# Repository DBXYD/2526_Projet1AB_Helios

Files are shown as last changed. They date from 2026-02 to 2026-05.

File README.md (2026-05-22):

# 2526_Projet1AB_Helios
Projet de 1ère année ENSEA sur un stroboscobe RGB
## Sommaire
* [Cahier des charges](#cahier-des-charges)
* [Matériels utilisés](#matériels-utilisés)
* [Organisation du projet](#organisation-du-projet)
  * [Architecture PCB](#architecture-pcb)
* [Journal de Bord du projet](#journal-de-bord-du-projet)
* [Répartition des Tâches](#répartition-des-tâches)
* [Membres du projet](#membres-du-projet)
## Cahier des charges
**Project scénique à LED**
* Strobe RGBW haute puissance (100 W minimum)
* Pilotage DMX512 (standard éclairage)
* interface utilisateur intuitive
* Modifier la fréquence d'allumage des LEDs
* Modes :
    * Intensité R/G/B
    * Strobe (fréquence, intensité)
* Sécurité thermique + électrique

**Contraintes**
* Alimentation secteur
* Fiabilité (usage scène)
* Dissipation thermique sérieuse
* Respect du DMX (isolation, timing)

## Présentation du projet
* [Présentation Hardware](https://github.com/DBXYD/2526_Projet1AB_Helios/blob/master/Presentation/Projet%201AB%20-%20H%C3%A9lios.pdf)
* [Architecture du Code](https://github.com/DBXYD/2526_Projet1AB_Helios/blob/master/Presentation/Projet1AB_Helios_Code.pdf) (DMX 512)

## Diagrammes
* [Diagrammes](https://github.com/DBXYD/2526_Projet1AB_Helios/tree/master/Presentation/Diagrammes)

## Matériels utilisés
| **Composant** | **Référence** |
| :--- | :--- |
| LEDs 98 (x3 couleurs) | [150505M173300](https://github.com/DBXYD/2526_Projet1AB_Helios/blob/master/datasheet/Datasheets%20du%20projet/LED_150505M173300.pdf) |
| 6 Driver | [LM3404](https://github.com/DBXYD/2526_Projet1AB_Helios/blob/master/datasheet/Datasheets%20du%20projet/lm3404.pdf) |
| Microcontrolleur | [STM32F103C6T6A LQFP-48](https://github.com/DBXYD/2526_Projet1AB_Helios/blob/master/datasheet/Datasheets%20du%20projet/stm32f103c6.pdf) |
| DMX512 | Mâle: [NC3MAAH](https://github.com/DBXYD/2526_Projet1AB_Helios/blob/master/datasheet/Datasheets%20du%20projet/nc3maah(DMX512M).pdf) Femelle: [NC3FAAH](https://github.com/DBXYD/2526_Projet1AB_Helios/blob/master/datasheet/Datasheets%20du%20projet/nc3faah(DMX512F).pdf) |
| Power Module WPME-FDSM | [173950536](https://github.com/DBXYD/2526_Projet1AB_Helios/blob/master/datasheet/Datasheets%20du%20projet/Power_Module_WPME-FDSM_173950536.pdf) |
| LOW DROPOUT LINEAR REGULATOR | [AZ1117CH2-TRG1](https://github.com/DBXYD/2526_Projet1AB_Helios/blob/master/datasheet/Datasheets%20du%20projet/AZ1117CH2-3.3TRG1.pdf) | 
| Ecran OLED | [OLED Dipslay](https://github.com/DBXYD/2526_Projet1AB_Helios/blob/master/datasheet/Datasheets%20du%20projet/SBC-OLED01_Datasheet_2022-01-06.pdf) |
| Alimentation | 24V / 5A | 
| Résistances | 2 x 1 kΩ ; 5 x 10 kΩ ; 2 x 1,6 kΩ ; 6 x 100 kΩ |
| Inductances | 6 x 18 uH |
| Condensateurs | 18 x 100 nF ; 2 x 1 uF ; 3 x 10 uF ; 1 x 22 uF ; 2 x 10 nF |
| LEDs SMD | 2 x [LED_0805_2012Metric](https://github.com/DBXYD/2526_Projet1AB_Helios/blob/master/datasheet/Datasheets%20du%20projet/LED_0805_2012Metric.pdf) |
| Boutons poussoirs | 3 x [Bouton ](https://github.com/DBXYD/2526_Projet1AB_Helios/blob/master/datasheet/Datasheets%20du%20projet/6x6_mm_sw_switches.pdf) |
| Puce MAX485E | [Puce](https://github.com/DBXYD/2526_Projet1AB_Helios/blob/master/datasheet/Datasheets%20du%20projet/MAX1487E-MAX491E.pdf) |
| Connecteur AMASS | [Connecteur 1](https://github.com/DBXYD/2526_Projet1AB_Helios/blob/master/datasheet/Datasheets%20du%20projet/XT30U-M_AMASS_Datasheet.pdf)|
| Connecteur PinHeader | [Connecteur 2](https://github.com/DBXYD/2526_Projet1AB_Helios/blob/master/datasheet/Datasheets%20du%20projet/connecteur%20pinheader.pdf)|

## Organisation du projet

### Architecture PCB:
* **Alimentation** : Power Module WPME-FSDM, AZ1117CH2-TRG1
* **Contrôle** : Microcontrolleur avec interface OLED
* **Pilotage LEDs** : drivers pour les chaînes R, G, B (2 drivers par couleur)
* **Protection et sécurité** : TODO (fusible, dissipateurs thermiques, diode)

### BOM:
[Matériel utilisé](https://github.com/DBXYD/2526_Projet1AB_Helios/blob/master/Hardware/KICAD_HELIOS/bom/ibom.html)

## Journal de Bord du projet 
[Journal de Bord](https://github.com/DBXYD/2526_Projet1AB_Helios/blob/master/journal_de_bord.md)

## Répartition des Tâches
| **Nom Prénom** | **Tâche(s)** |
| :--- | :--- |
| **TRITON Kylian** | Schématique du PCB, Routage du PCB, Valeurs des composants (fichier python), Mise à jour du Github, Recherche des composants |
| **RIEU Pierric** | Software des drivers (intégralité des codes), PCB |
| **BAILLEUL Sara** | Soudage, Vérification des empreintes sur PCB, Commande des composants et bon de commande du PCB, Recherche des composants (soudage et datasheet), Mise à jour du GitHub, Diagramme Hardware |
| **LEIRAS Clara** | LEDs (Schématique du PCB), Soudage, Recherche des composants (datasheet) |
| **GOMRI Samuel** | Recherche des composants |

## Membres du projet
| | | | | |
|:---:|:---:|:---:|:---:|:---:|
|  |  |  |  |  | 
| [**@TritonKylian**](https://github.com/TritonKylian)<br>TRITON Kylian| [**@PierricRieu**](https://github.com/PierricRieu)<br>RIEU Pierric | [**@sblikeice**](https://github.com/sblikeice)<br> BAILLEUL Sara | [**@claralrs9**](https://github.com/claralrs9)<br>LEIRAS Clara| [**@sgomri**](https://github.com/sgomri)<br>GOMRI Samuel |

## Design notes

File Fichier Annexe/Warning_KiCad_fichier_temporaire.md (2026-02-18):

# Warning KiCad (Document temporaire)
## cathode
la cathode peut être branché à rien (il n'y a plus aucune erreur), /edit/ normalement c'est ok.
## LED Footprint 
could be wrong for the D1 and D2
## Ecran
Doit-on utiliser un socket ou bien alors un connecteur pour l'écran (practicité etc à voir ou alors le brancher en usb???)
## Résistance
Vérifier les bonnes valeurs des empreintes: 
ie: 2010 pour les grosses et 1210 pour autres
et pour les résistances de pull up 0805
## Bouton 
jsp ce qu'ils ont de dispo à l'école mais j'ai assumé qu'ils en ont pleins différents (j'ai ni datasheet ni bouton sur l'excel)
# Schéma 
## LED arragement 
Pour le soudage il faut obligatoirement faire un schéma à partir des connections avant de les faire puisque les leds ne sont pas aligné correctement il faut les remettre en place

**Auteur :** Triton Kylian
**Date :** 19 Février 2026
**Statut :** En attente de validation des empreintes et du schéma dans l'intégralité

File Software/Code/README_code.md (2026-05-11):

# 2526_Projet1AB_Helios
Projet de 1ere année ENSEA sur un strobe

* TRITON Kylian
* RIEU Pierric
* BAILLEUL Sara
* LEIRAS Clara
* GOMRI Samuel

## CODE POUR ALLUMER LES LEDS

* Code pour allumer la led (Red) Rouge
* Code pour allumer la led (Green) Vert
* Code pour allumer la led (Blue) Bleu
* Code pour Dimmer(intensité)
* Code pour Shutter (fréquence)

* Penser à codé l'addresse pour chaque LED 512B envoyé 20 fois par s

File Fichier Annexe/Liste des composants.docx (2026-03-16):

Liste des composants et quantité nécessaire :

Empreinte

En stock : sur l’Excel

P : demander à Patricia avant pour savoir si ce n’est pas en stock autre part

Microcontrôleur : STM32F103C6TX (1) → à commander

Condensateurs (26) :

- 100 nF (18) → en stock → 0603/50V sinon 0402
- 1 uF (2) → en stock → 0402 (si pas plus de 10V à l’endroit où il est)
- 10 uF (3) → (1 à côté du 24V, donc à commander MLCCs → 50V max/1206) et 0603/0805 (kit) (+5V) → 2 C
- 22 uF (1) → en stock (0805)
- 10 nF (2) → en stock → 0402

LEDs :

- Celle : LED_0805_2012Metric (2) → à voir, à commander P
- Pour l’éclairage : LEDWL-SFTW_5050_PLCC6 (98x3) / 150505M173300 → à commander

Connecteurs :

- Mâle : NC3MAAH (1) → en stock (boîte du projet)
- Femelle : NC3FAAH (1) → en stock (boîte du projet)
- Pour contrôler certains labels : Conn_ST_STDC14 (1) → en stock (normalement) P

lien DMX et microcontrôleur : MAX485E (1) → à commander P

Ecran OLED (1) → en stock

Bobines (6) :

- 68 uH (2) (1210) → en stock
- 18 uH (4) (1210) → à commander P

Résistances (15) :

- 1 kΩ (2) (1210) → à commander (en stock : 1206/0603/0402) P
- 10 kΩ (5) (1210 x4 et 0805x1) → 1210 à commander et 0805 en stock P
- 1,6 kΩ (2) (1210) → à commander P
- 100 kΩ (6) (2010) → à commander (en stock : 1206/0805) P

Bouton poussoir (3) → en stock

Drivers (6) :

- LM3404MA (6) → en stock (8)

Alimentation :

- AMS1117-3.3 (1) → à commander P
- R-78B5.0-2.0 (1) → à commander (il n’y en a plus en stock sur le Excel) P

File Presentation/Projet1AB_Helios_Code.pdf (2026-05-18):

# Projet1AB Helios

# Architecture du code

# Table des matières

## 1. Architecture globale 2. DMX512 : explication 3. Le module DMX 4. Le module DMX_PARSE 5. Le module STROBE 6. Difficultés rencontrées et apprentissages 7. Bibliographie

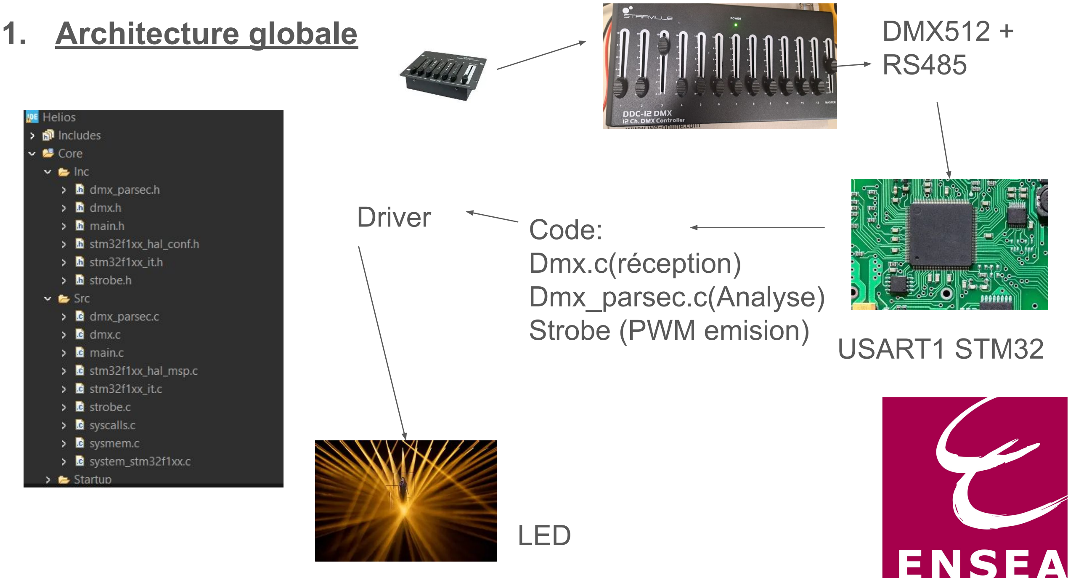
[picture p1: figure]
Architecture globale; DMX512 +; USART1 STM32; Driver; LED; Code: Dmx.c(réception) Dmx_parsec.c(Analyse) Strobe (PWM emision)

La norme DMX512 fonctionne par envoi d’octets pour chaque channel (donc de 0 à 255 codé sur 8 bits).

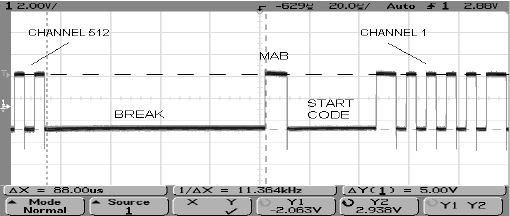
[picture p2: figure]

Cela va nous permettre d’établir l’intensité de chaque channel avec une PWM sur notre driver, selon la formule :

intensité = (valeur du channel × intensité du master) / 255

2. DMX512 : Explication | La norme DMX512 est un protocole d’éclairage numérique
| utilisé dans le domaine du spectacle et de la scène. Elle repose sur une communication série RS-485.Le protocole DMX512 permet de transmettre jusqu’à 512 canaux et fonctionne selon une architecture maître → esclaves : une console maître peut commander plusieurs équipements esclaves. Nous utilisons le RS-485 et non le RS-422 car le RS-485 est plus adapté aux systèmes DMX. Bien que les deux utilisent une transmission différentielle, le RS-485 permet d’avoir plusieurs équipements sur le même bus, contrairement au RS-422 qui ne supporte qu’un seul émetteur. Ainsi, plusieurs appareils peuvent être connectés sur la même ligne : projecteurs, strobes, machines à fumée, etc. Le RS-485 possède également une forte immunité aux parasites électriques et est adapté aux communications sur de longues distances.

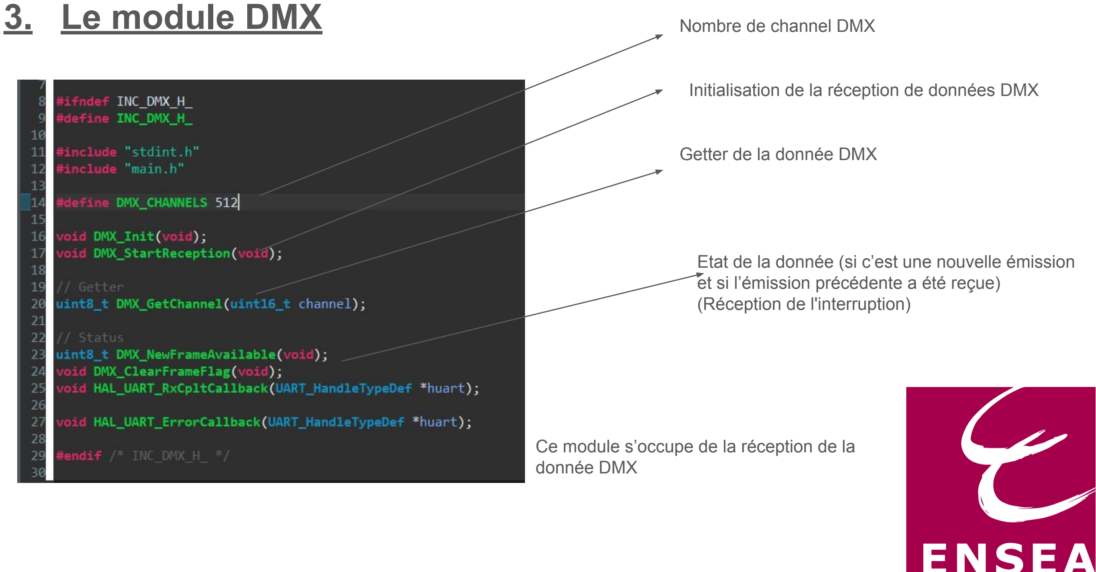
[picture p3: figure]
Le module DMX; Nombre de channel DMX; Getter de la donnée DMX; (Réception de l'interruption); donnée DMX

Initialisation de la réception de données DMX

Etat de la donnée (si c’est une nouvelle émission et si l’émission précédente a été reçue)

Ce module s’occupe de la réception de la

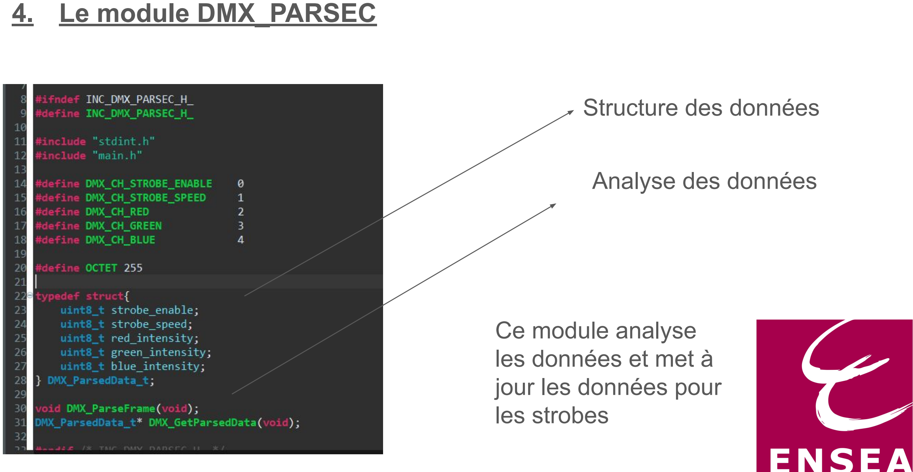
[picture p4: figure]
4. Le module DMX_PARSEC; Structure des données; Analyse des données; Ce module analyse les données et met à jour les données pour les strobes

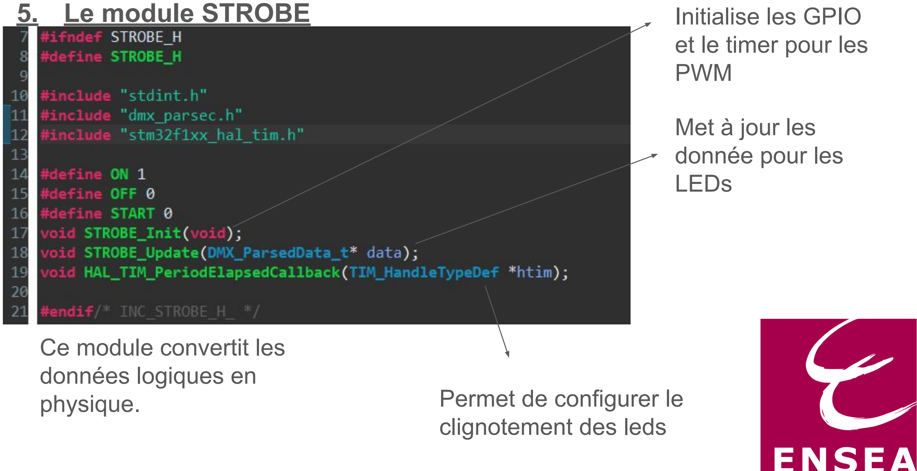
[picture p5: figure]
Le module STROBE; Initialise les GPIO; et le timer pour les PWM; Met à jour les donnée pour les LEDs; Ce module convertit les données logiques en; physique.; Permet de configurer le; clignotement des leds

# 6. Difficultés rencontrées et apprentissages

### Difficultés rencontrées : - Manque de temps pour tester le bon fonctionnement du code

- Surchauffe du PCB empêchant certains tests .

### - Erreur lors du routage sur l’association des pins : Driver de LEDG2 et LEDB2 ont été connectés à des pins ne disposant pas de la fonction TIMER ( Solution mise en place : Création d’une PWM software pour piloter les LEDs concernées )

### Apprentissages : - Utilisation de l'oscilloscope pour visualiser l’émission et la réception des trames DMX

- Rédaction d’un code plus propre et modulaire avec l’utilisation de getter, setter et machine à état.

### - L’importance du choix et du branchement des pins lors du routage et de

la conception du schématique.

# 7. Bibliographie

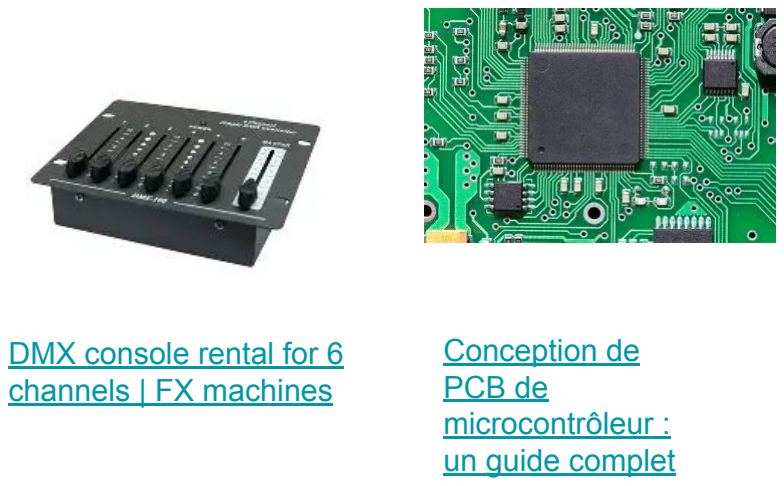
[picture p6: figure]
DMX console rental for 6 channels | FX machines; Conception de PCB de microcontrôleur : un guide complet
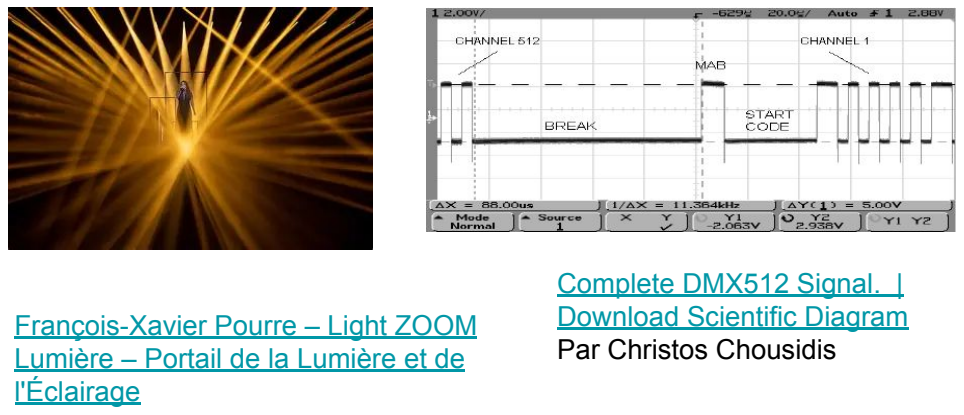
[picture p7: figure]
François-Xavier Pourre – Light ZOOM Lumière – Portail de la Lumière et de l'Éclairage; Complete DMX512 Signal. | Download Scientific Diagram Par Christos Chousidis

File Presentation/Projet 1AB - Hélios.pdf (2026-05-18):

# Hélios Projet de Strobe Led

# Kylian TRITON - Pierric RIEU - Sara BAILLEUL - Clara LEIRAS - Samuel GOMRI

## FISE 1AB

2026

# Définition des enjeux du projet

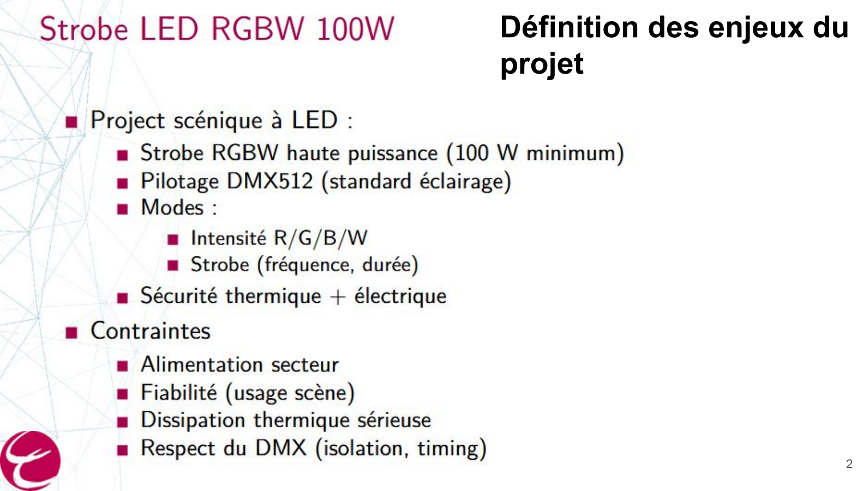
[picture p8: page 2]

# Schématique du PCB

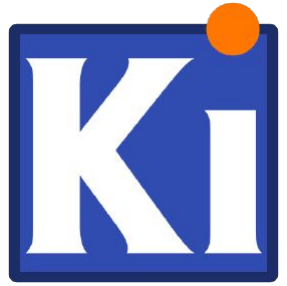
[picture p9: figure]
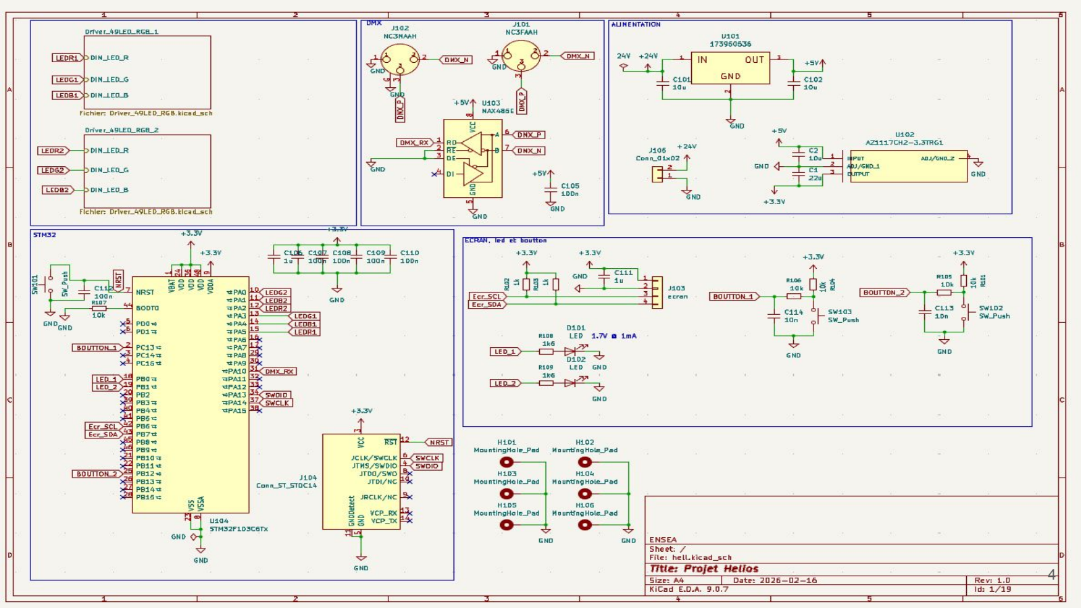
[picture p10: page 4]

# Problème rencontré

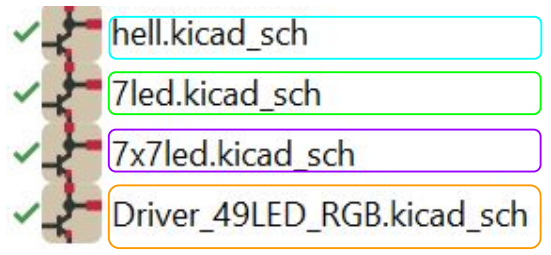
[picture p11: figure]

- pas assez de place pour mettre tout sur une seule page

# Solution trouvée

- création de plusieurs pages : une pour les drivers et une pour les LEDs qu’on copie colle autant de fois que nécessaire

Page pour 3 drivers de
LED

Assemblage de 7 LEDs

7 fois l’assemblage de 7
LEDs

Schématique complet

# Problèmes et solutions

# Les pages (1)

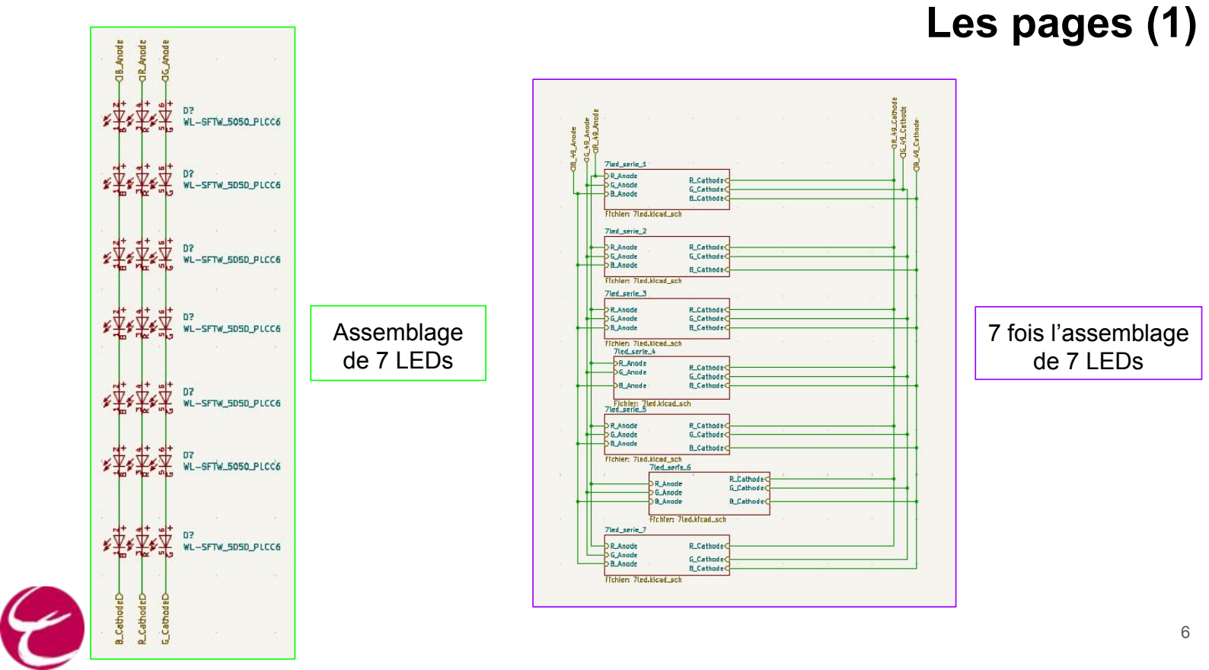
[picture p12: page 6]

Assemblage
de 7 LEDs

7 fois l’assemblage
de 7 LEDs

# Les pages (2)

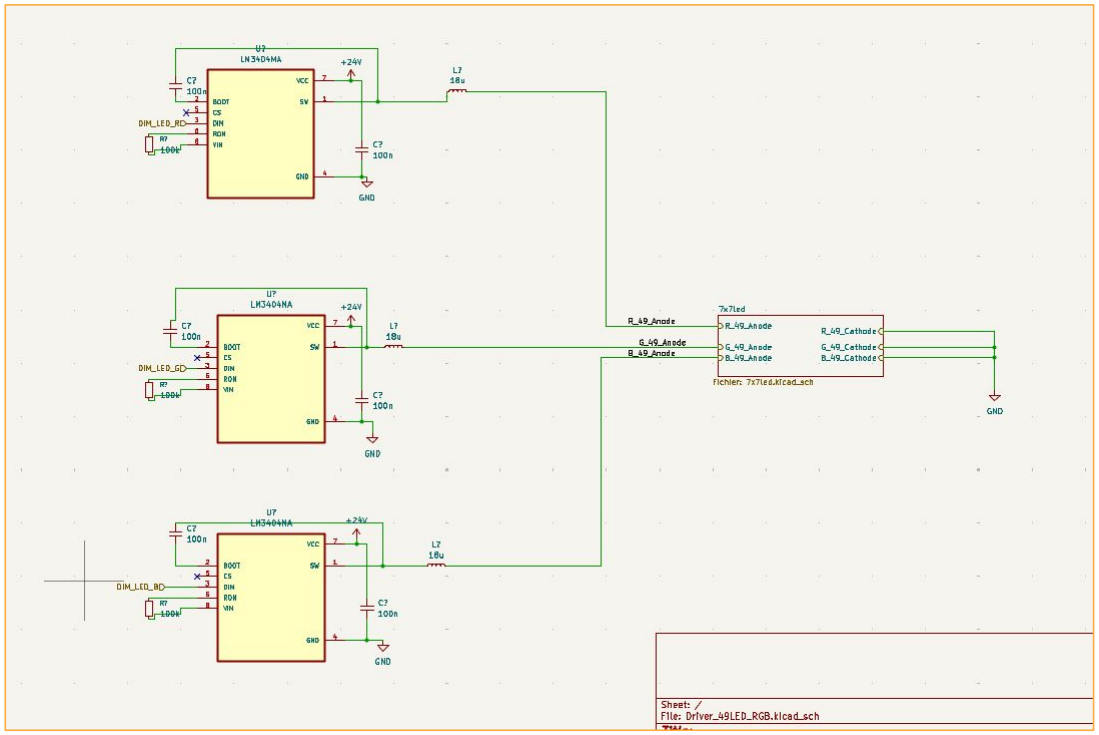
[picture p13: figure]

Page pour 3
drivers de LED
(x2 dans le
schématique
final)

# Routage du PCB

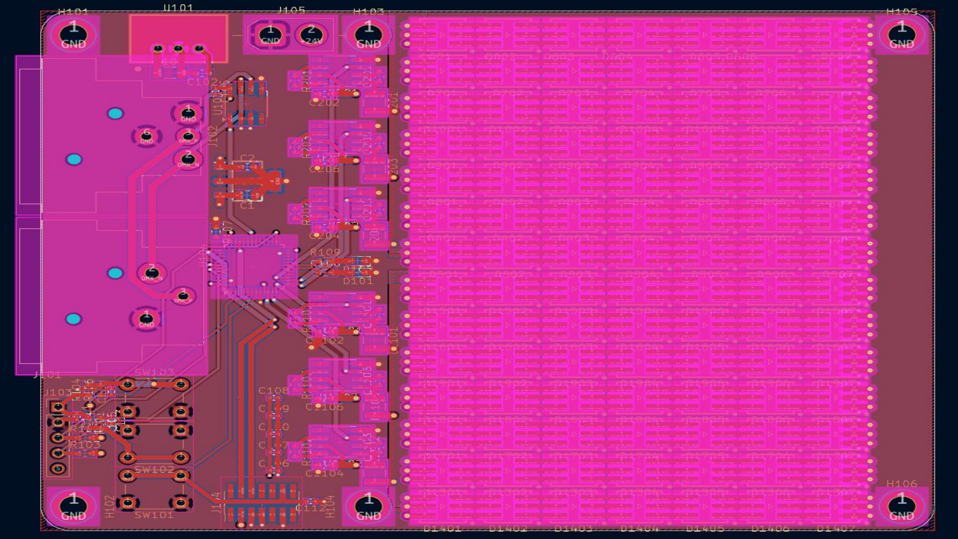
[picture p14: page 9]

# Problème rencontré

- Le PCB devient vite très imposant avec le nombre de LEDs

# Solution trouvée

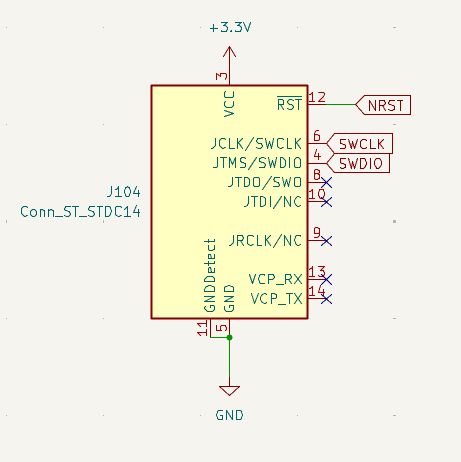
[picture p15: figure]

- Création de plusieurs couches avec différents potentiels pour connecter les composants et réduire l’encombrement. Utilisation de grille pour bien aligner les pièces sur le PCB.
- Placement de la connectique de l’écran sur le bord du PCB.
- Certains composants prennent plus de place (niveau mécanique que l’affichage de leur connectique sur Kicad

# Problèmes et solutions

# Soudage du PCB

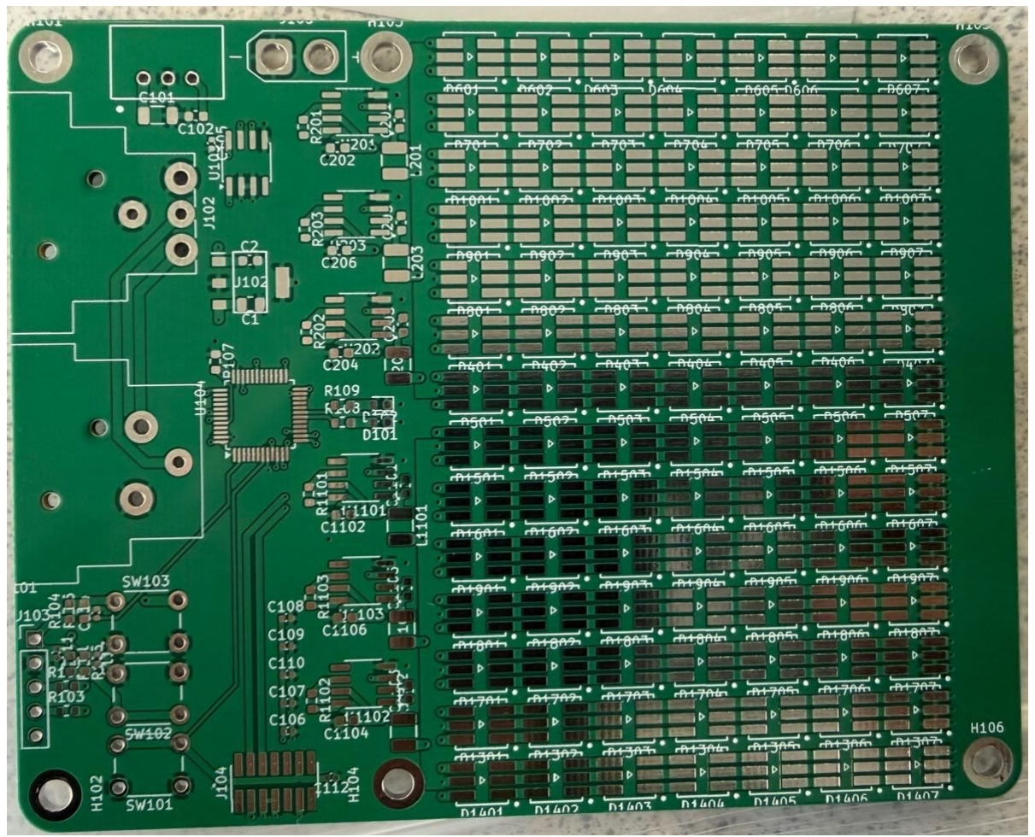
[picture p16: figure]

2 étapes :
- Pâte à braser et four
- Soudage à la main
avec fer à souder et
étain

# Recherche des composants

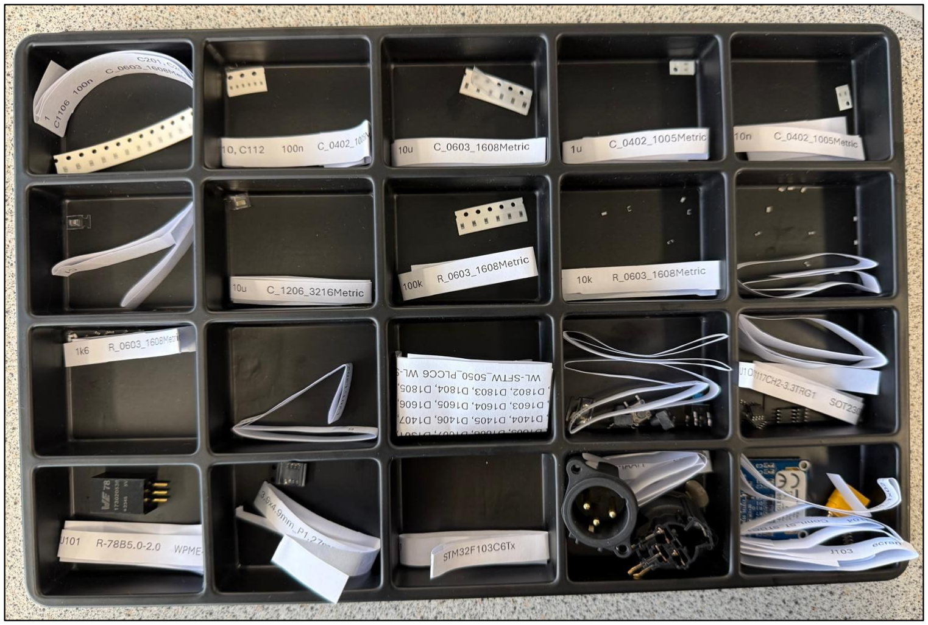
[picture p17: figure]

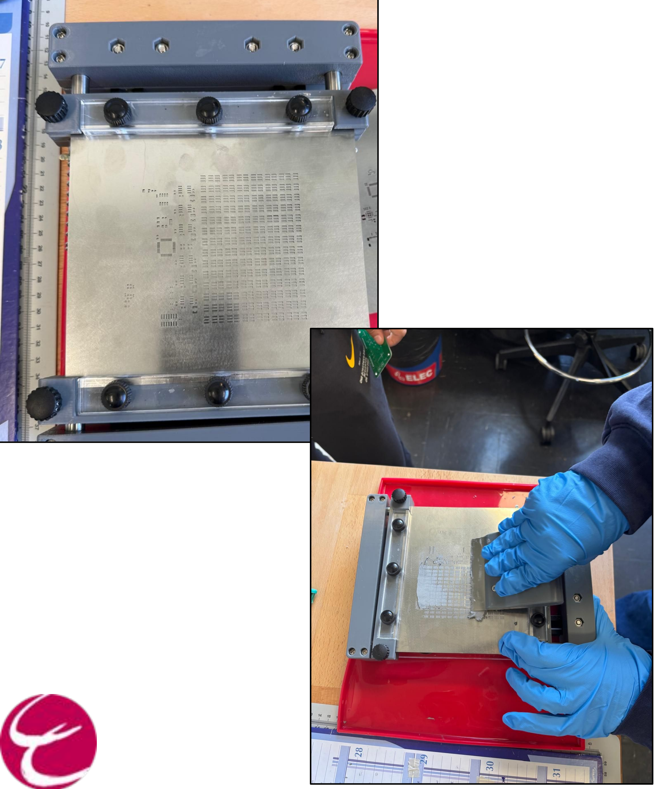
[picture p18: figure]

# Pâte à braser

## Déroulement : - Aligner le STENCIL avec le PCB grâce aux roulettes de calage et immobilier l’ensemble - Appliquer la pâte à braser avec des gants, sur toute la surface des trous du STENCIL grâce à la raclette

# Positionnement des composants

## Déroulement :

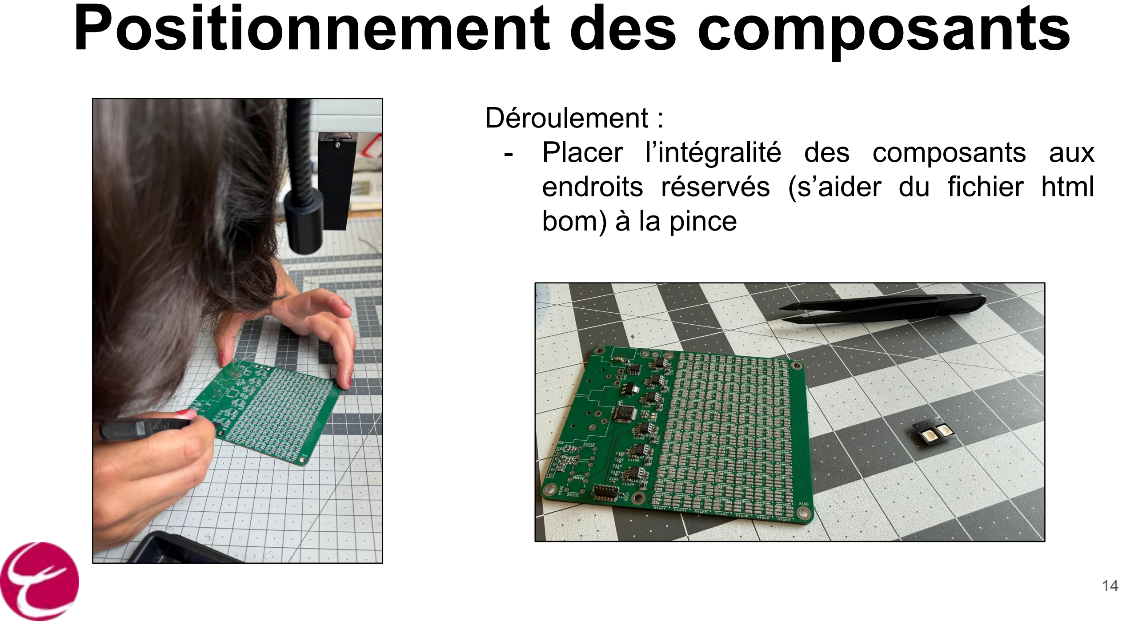
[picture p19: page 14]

## - Placer l’intégralité des composants aux endroits réservés (s’aider du fichier html bom) à la pince

# Four

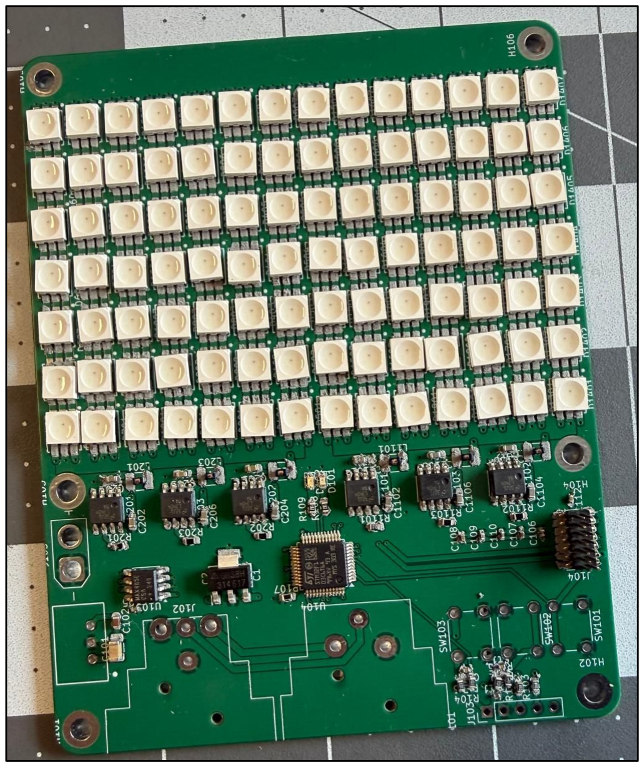
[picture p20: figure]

## Déroulement : - Placer le PCB pendant 5 minutes au four (et refaire au besoin si le soudage ne s’est pas fait totalement car le PCB est assez gros)

# Sortie du four

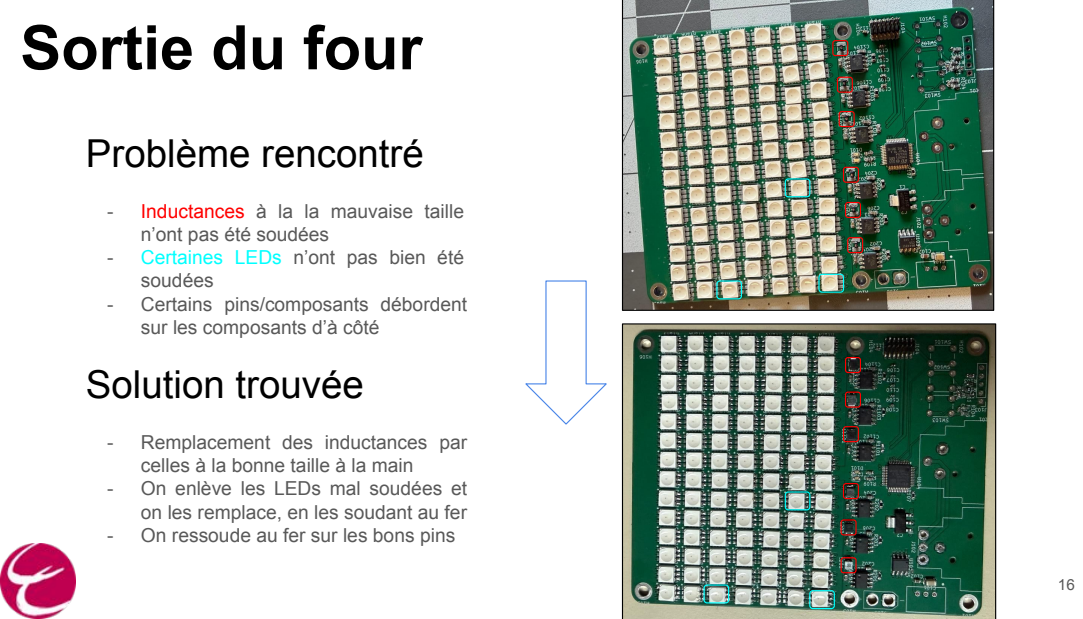
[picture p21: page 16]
Problème rencontré -; Inductances à la la mauvaise taille; Solution trouvée -; Remplacement des inductances par

n’ont pas été soudées
- Certaines LEDs n’ont pas bien été
soudées
- Certains pins/composants débordent
sur les composants d’à côté

celles à la bonne taille à la main
- On enlève les LEDs mal soudées et
on les remplace, en les soudant au fer
- On ressoude au fer sur les bons pins

# Fer à souder et étain

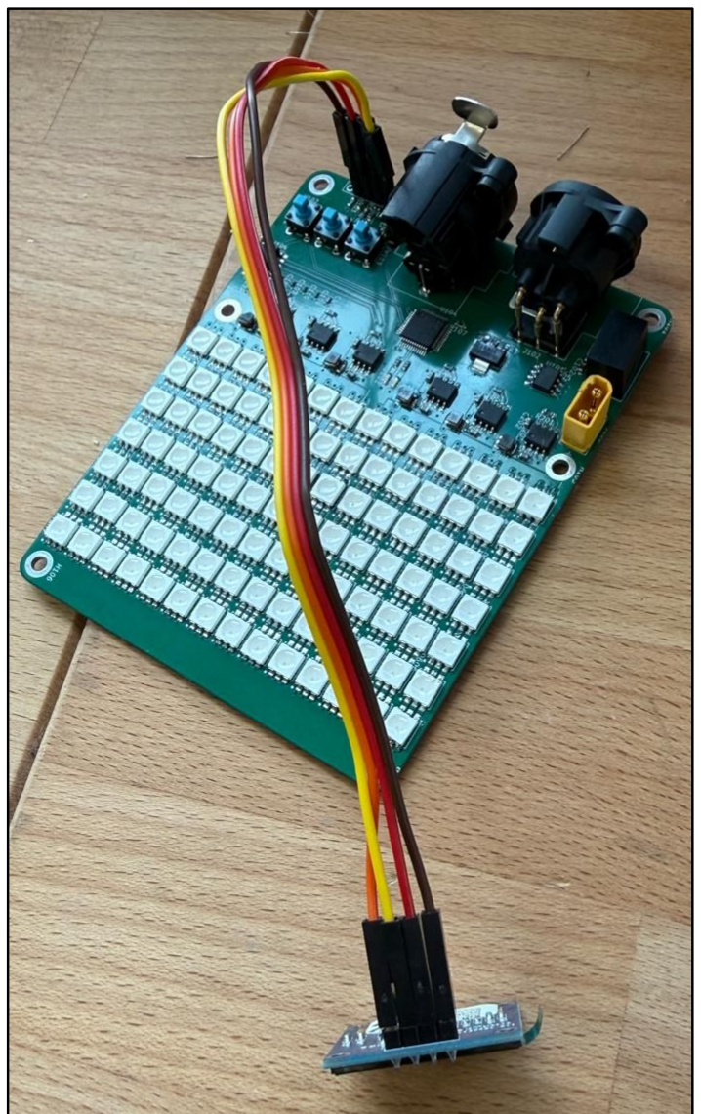
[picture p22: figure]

## Déroulement : - On soude avec de l’étain et un fer à souder tous les composants traversants (la majorité à souder au niveau du dos du PCB)

# Fer à souder et étain

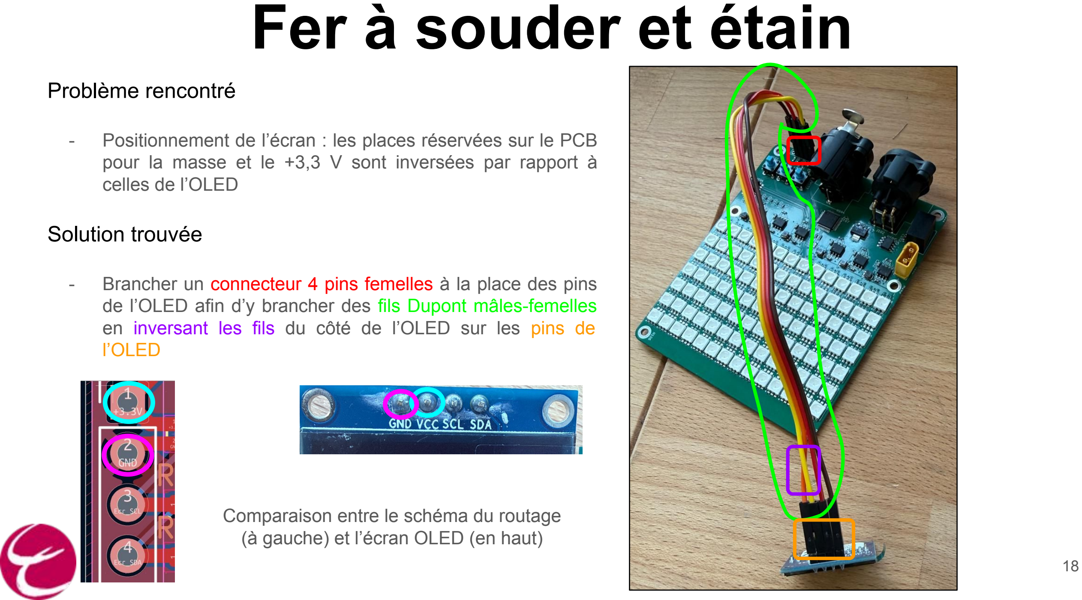
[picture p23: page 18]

Problème rencontré

- Positionnement de l’écran : les places réservées sur le PCB pour la masse et le +3,3 V sont inversées par rapport à celles de l’OLED

Solution trouvée

- Brancher un connecteur 4 pins femelles à la place des pins de l’OLED afin d’y brancher des fils Dupont mâles-femelles en inversant les fils du côté de l’OLED sur les pins de l’OLED

Comparaison entre le schéma du routage (à gauche) et l’écran OLED (en haut)

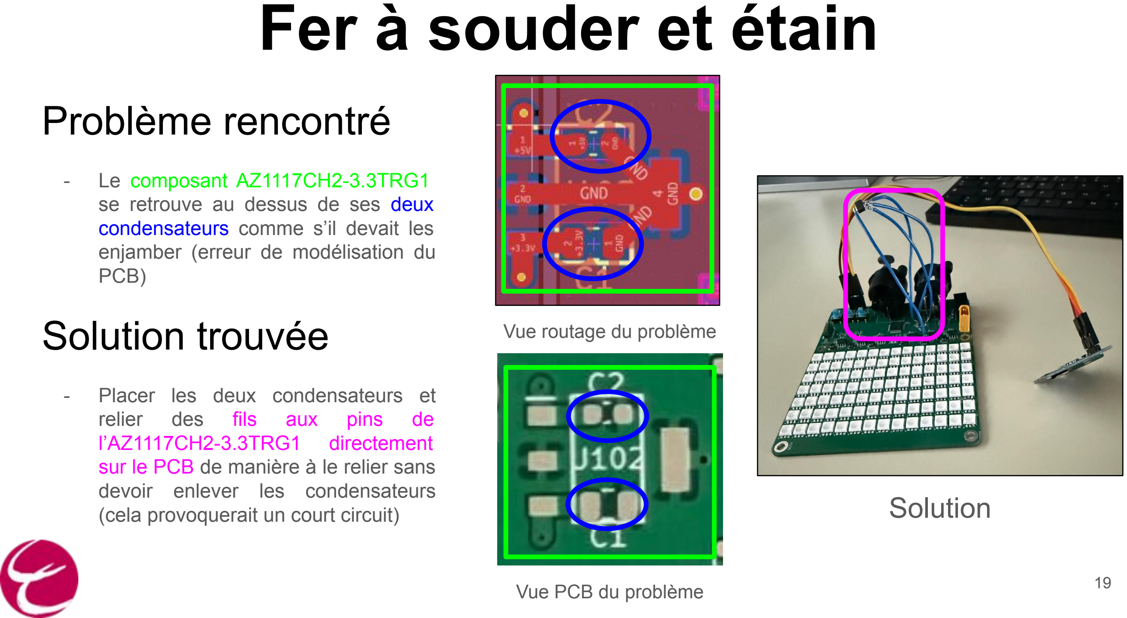
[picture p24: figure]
Fer à souder et étain; Problème rencontré; - Le composant AZ1117CH2-3.3TRG1 se retrouve au dessus de ses deux condensateurs comme s’il devait les enjamber (erreur de modélisation du PCB) Solution trouvée; - Placer les deux condensateurs et; relier; des; fils; aux; pins; l’AZ1117CH2-3.3TRG1; directement; sur le PCB de manière à le relier sans devoir enlever les condensateurs (cela provoquerait un court circuit); Vue routage du problème; Vue PCB du problème; Solution

# Vérification des courts-circuits


## - Vérification des bons branchements entre masse/ masse et alimentation/ alimentation

## - A priori, les branchements étaient opérationnels

# Allumage des LEDs : phase de test de fonctionnement


- Les | LEDs | s’allument
progressivement | selon
l’augmentation | de | la
tension, | d’abord | elles

## éclairent faiblement puis à pleine puissance

Allumage des LEDs; Problème rencontré; Solution trouvée (à implémenter); valeur qui acceptent 0.56 A ou plus.

- Les inductances chauffent et grillent car le courant supporté par les inductances n’est pas suffisant par rapport à celui des LEDs. Elles supportent du 0.24 A et elles devraient pouvoir supporter un courant de 7x0.080 = 0.56 A
- Remplacer les bobines actuelles par des bobines de même

# Sensibilisation environnementale et éthique

Votre projet limite-t-il les facteurs susceptibles de représenter des dangers pour la personne (accidents, conditions de travail, milieu de vie, mobilité...) ?

### 1. Sécurité électrique et protection des personnes

- Problème : L’émetteur-récepteur DMX MAX485E est connecté directement au microcontrôleur ce qui implique que la masse du MAX485E et celle du STM sont directement reliées. S’il y a un problème, la surtension se propage au microcontrôleur et toute la carte grille. Il existe donc un réel risque pour l’environnement et la personne si la carte prend feu.
- Solutions : 1) Refaire le PCB en intégrant une isolation galvanique via un optocoupleur (6N137) : seul le MAX485E serait détruit car les masses seront isolées. ou 2) Intercaler un boîtier isolateur DMX galvanique externe qui va recevoir tous les chocs électriques et renvoyer un signal sécurisé vers le PCB.

### 2. Robustesse et durabilité

- Les boutons intègrent des filtres RC pour un anti-rebond matériel et les lignes I2C bénéficient de résistances de pull-up
- Alimentation générale à +24V et alimentation régulée à 2 étages pour la partie commande : +5V (U101) pour le MAX485E et +3.3V (U102) pour la STM

### 3. Conception hiérarchisée et écologique

- Consommation d’énergie régulée par le DMX (contrôle du rapport cyclique)
- Blocs hiérarchisés : partie puissance séparée de la partie commande ce qui facilite les réparations ou la réutilisation de certaines parties du système


Boutons


Régulation de
l’alimentation

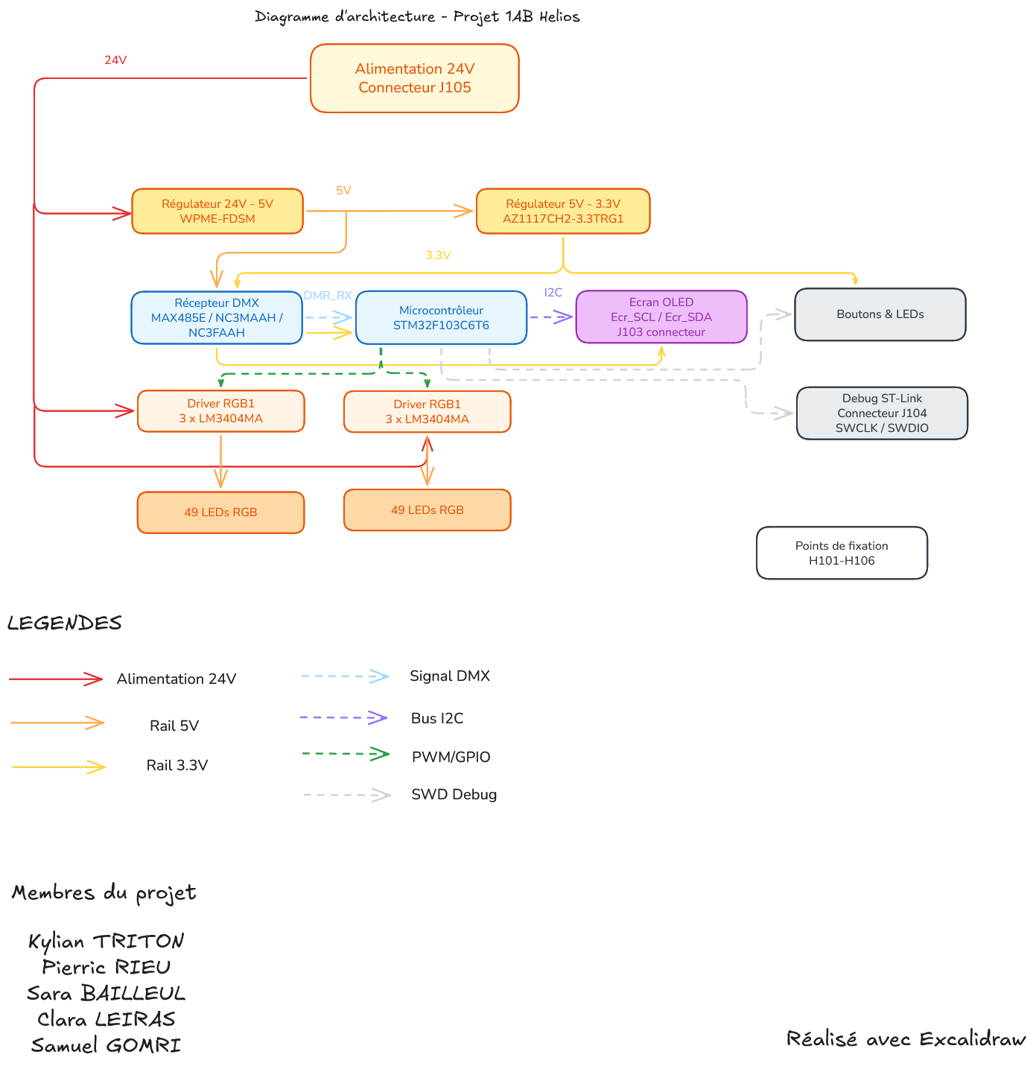
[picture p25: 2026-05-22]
Presentation/Diagrammes/Diagramme Hardware-Helios.png

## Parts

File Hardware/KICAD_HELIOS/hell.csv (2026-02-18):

Reference | Qty | Value | DNP | Exclude from BOM | Exclude from Board | Footprint | Datasheet
C1,C2,C3,C4,C6,C7,C11,C12,C13,C14,C15,C16,C17,C18,C19,C20,C21,C22,C23 | 19 | 100n |  |  |  | Capacitor_SMD:C_0805_2012Metric | ~
C5 | 1 | 1u |  |  |  | Capacitor_SMD:C_0805_2012Metric | ~
C8,C9 | 2 | 10u |  |  |  | Capacitor_SMD:C_0805_2012Metric | ~
C10 | 1 | 100u |  |  |  | Capacitor_SMD:C_0805_2012Metric | ~
D1,D2 | 2 | LED |  |  |  | LED_SMD:LED_0805_2012Metric | ~
D3,D4,D5,D6,D7,D8,D9,D10,D11,D12,D13,D14,D15,D16,D17,D18,D19,D20,D21,D22,D23,D24,D25,D26,D27,D28,D29,D30,D31,D32,D33,D34,D35,D36,D37,D38,D39,D40,D41,D42,D43,D44,D45,D46,D47,D48,D49,D50,D51,D52,D53,D54,D55,D56,D57,D58,D59,D60,D61,D62,D63,D64,D65,D66,D67,D68,D69,D70,D71,D72,D73,D74,D75,D76,D77,D78,D79,D80,D81,D82,D83,D84,D85,D86,D87,D88,D89,D90,D91,D92,D93,D94,D95,D96,D97,D98,D99,D100 | 98 | WL-SFTW_5050_PLCC6 |  |  |  | LED:WL-SFTW_5050_PLCC6
J1 | 1 | Conn_01x05 |  |  |  | Connector_PinHeader_2.54mm:PinHeader_1x05_P2.54mm_Vertical | ~
J3 | 1 | NC3FAAH |  |  |  | Connector_Audio:Jack_XLR_Neutrik_NC3FAAH_Horizontal | https://www.neutrik.com/en/product/nc3faah
J4 | 1 | NC3MAAH |  |  |  | Connector_Audio:Jack_XLR_Neutrik_NC3MAAH_Horizontal | https://www.neutrik.com/en/product/nc3maah
J5 | 1 | ecran |  |  |  | Connector_PinHeader_2.54mm:PinHeader_1x05_P2.54mm_Vertical | ~
L1,L2,L3,L4,L5,L6 | 6 | 50u |  |  |  | Inductor_SMD:L_1210_3225Metric | ~
R1,R2 | 2 | 10k |  |  |  | Resistor_SMD:R_0805_2012Metric | ~
R3,R4 | 2 | 330 |  |  |  | Resistor_SMD:R_1210_3225Metric | ~
R7,R8,R9,R10,R11,R12 | 6 | 100k |  |  |  | Resistor_SMD:R_2010_5025Metric | ~
SW1,SW2 | 2 | SW_Push |  |  |  | Button_Switch_THT:SW_PUSH_6mm | ~
U1 | 1 | STM32F103C6Tx |  |  |  | Package_QFP:LQFP-48_7x7mm_P0.5mm | https://www.st.com/resource/en/datasheet/stm32f103c6.pdf
U2 | 1 | AMS1117-3.3 |  |  |  | Package_TO_SOT_SMD:SOT-223-3_TabPin2 | http://www.advanced-monolithic.com/pdf/ds1117.pdf
U3 | 1 | MAX485E |  |  |  | Package_SO:SOIC-8_3.9x4.9mm_P1.27mm | https://datasheets.maximintegrated.com/en/ds/MAX1487E-MAX491E.pdf
U4 | 1 | R-78B2.5-2.0 |  |  |  | Converter_DCDC:Converter_DCDC_RECOM_R-78B-2.0_THT | https://www.recom-power.com/pdf/Innoline/R-78Bxx-2.0.pdf
U5,U6,U7,U8,U9,U10 | 6 | LM3404MA |  |  |  | LM3404MA:SOIC127P599X175-8N

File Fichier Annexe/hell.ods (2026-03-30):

Reference | Qty | Value | Footprint | Datasheet | MPN
C101 | 1 | 10u | Capacitor_SMD:C_1206_3216Metric | ~
C102,C103 | 2 | 10u | Capacitor_SMD:C_0603_1608Metric | ~
C104 | 1 | 22u | Capacitor_SMD:C_0805_2012Metric | ~
C105,C107,C108,C109,C110,C112 | 6 | 100n | Capacitor_SMD:C_0402_1005Metric | ~
C106,C111 | 2 | 1u | Capacitor_SMD:C_0402_1005Metric | ~
C113,C114 | 2 | 10n | Capacitor_SMD:C_0402_1005Metric | ~
C201,C202,C203,C204,C205,C206,C1101,C1102,C1103,C1104,C1105,C1106 | 12 | 100n | Capacitor_SMD:C_0603_1608Metric | ~
D101,D102 | 2 | LED | LED_SMD:LED_0805_2012Metric | ~ | 150060RS55040
D401,D402,D403,D404,D405,D406,D407,D501,D502,D503,D504,D505,D506,D507,D601,D602,D603,D604,D605,D606,D607,D701,D702,D703,D704,D705,D706,D707,D801,D802,D803,D804,D805,D806,D807,D901,D902,D903,D904,D905,D906,D907,D1001,D1002,D1003,D1004,D1005,D1006,D1007,D1301,D1302,D1303,D1304,D1305,D1306,D1307,D1401,D1402,D1403,D1404,D1405,D1406,D1407,D1501,D1502,D1503,D1504,D1505,D1506,D1507,D1601,D1602,D1603,D1604,D1605,D1606,D1607,D1701,D1702,D1703,D1704,D1705,D1706,D1707,D1801,D1802,D1803,D1804,D1805,D1806,D1807,D1901,D1902,D1903,D1904,D1905,D1906,D1907 | 98 | WL-SFTW_5050_PLCC6 | LED:WL-SFTW_5050_PLCC6
H101,H102,H103,H104,H105,H106 | 6 | MountingHole_Pad | MountingHole:MountingHole_3.2mm_M3_DIN965_Pad | ~
J101 | 1 | NC3FAAH | Connector_Audio:Jack_XLR_Neutrik_NC3FAAH_Horizontal | https://www.neutrik.com/en/product/nc3faah | NC3FAAH
J102 | 1 | NC3MAAH | Connector_Audio:Jack_XLR_Neutrik_NC3MAAH_Horizontal | https://www.neutrik.com/en/product/nc3maah | NC3MAAH
J103 | 1 | ecran | Connector_PinHeader_2.54mm:PinHeader_1x05_P2.54mm_Vertical | ~
J104 | 1 | Conn_ST_STDC14 | Connector_PinHeader_1.27mm:PinHeader_2x07_P1.27mm_Vertical_SMD | https://www.st.com/content/ccc/resource/technical/document/user_manual/group1/99/49/91/b6/b2/3a/46/e5/DM00526767/files/DM00526767.pdf/jcr:content/translations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 | -
J105 | 1 | Conn_01x02 | Connector_AMASS:AMASS_XT30U-M_1x02_P5.0mm_Vertical | ~
L201,L1101 | 2 | 68u | Inductor_SMD:L_1210_3225Metric | ~ |  |  | 744045680 | 1812
L202,L203,L1102,L1103 | 4 | 18u | Inductor_SMD:L_1210_3225Metric | ~ |  |  | 744032180 | 1210
R101 | 1 | 10k | Resistor_SMD:R_1210_3225Metric | ~ |  |  |  | 0603
R102,R103 | 2 | 1k | Resistor_SMD:R_1210_3225Metric | ~ |  |  |  | 0603
R104,R105,R106,R107 | 4 | 10k | Resistor_SMD:R_0805_2012Metric | ~ |  |  |  | 0603
R108,R109 | 2 | 1k6 | Resistor_SMD:R_1210_3225Metric | ~ |  |  |  | 0603
R201,R202,R203,R1101,R1102,R1103 | 6 | 100k | Resistor_SMD:R_2010_5025Metric | ~ |  |  |  | 0603
SW101,SW102,SW103 | 3 | SW_Push | Button_Switch_THT:SW_PUSH_6mm | ~
U101 | 1 | R-78B5.0-2.0 | Converter_DCDC:Converter_DCDC_RECOM_R-78B-2.0_THT | https://www.recom-power.com/pdf/Innoline/R-78Bxx-2.0.pdf | - | 24V → 5V | 173950536
U102 | 1 | AMS1117-3.3 | Package_TO_SOT_SMD:SOT-223-3_TabPin2 | http://www.advanced-monolithic.com/pdf/ds1117.pdf | - |  | AZ1117CH2-TRG1
U103 | 1 | MAX485E | Package_SO:SOIC-8_3.9x4.9mm_P1.27mm | https://datasheets.maximintegrated.com/en/ds/MAX1487E-MAX491E.pdf | -
U104 | 1 | STM32F103C6Tx | Package_QFP:LQFP-48_7x7mm_P0.5mm | https://www.st.com/resource/en/datasheet/stm32f103c6.pdf | -
U201,U202,U203,U1101,U1102,U1103 | 6 | LM3404MA | LM3404MA:SOIC127P599X175-8N

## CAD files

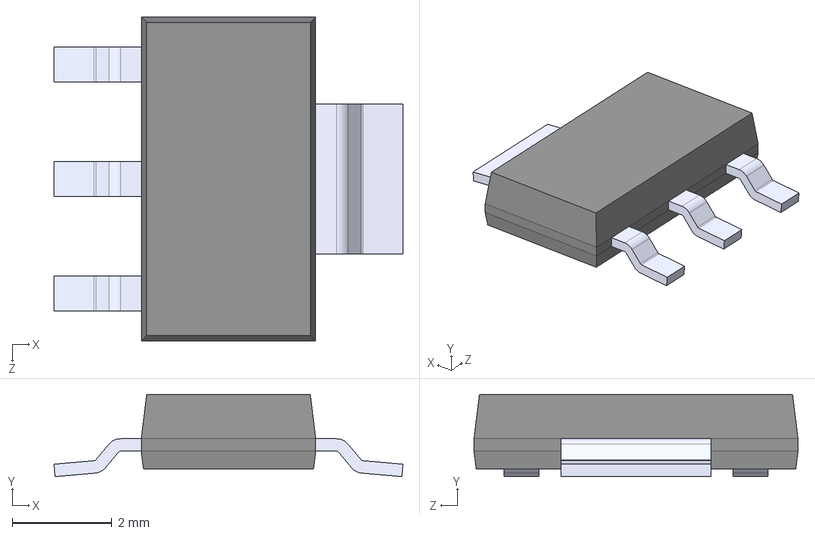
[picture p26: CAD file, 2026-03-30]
Hardware/KICAD_HELIOS/Composants_Helios_KiCad/AZ1117CH2-3.3TRG1/AZ1117CH2-3.3TRG1.step
7.00 x 1.65 x 6.50 mm

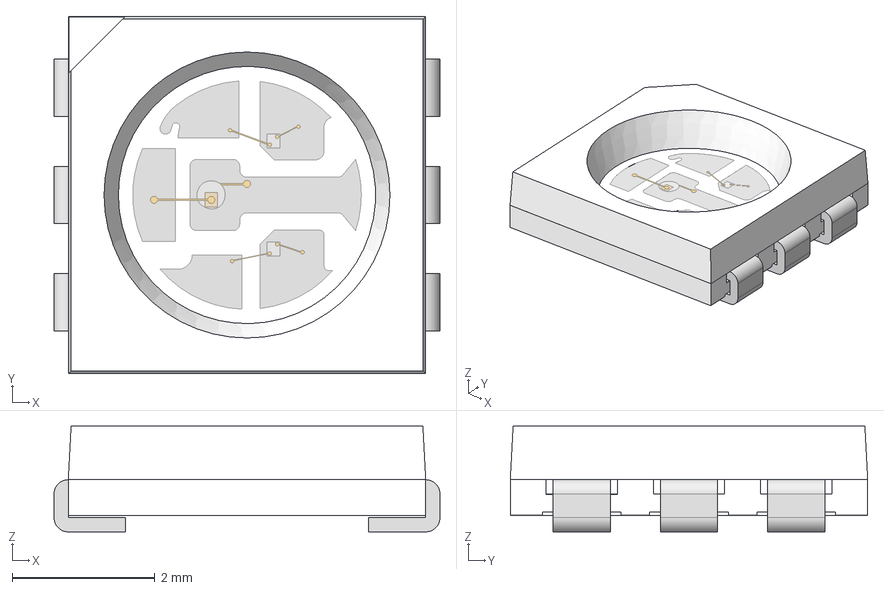
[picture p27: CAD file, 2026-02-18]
Hardware/KICAD_HELIOS/Composants_Helios_KiCad/LED/WL-SFTW_5050_PLCC6.step
5.40 x 5.00 x 1.48 mm
cover
housing
base x 2

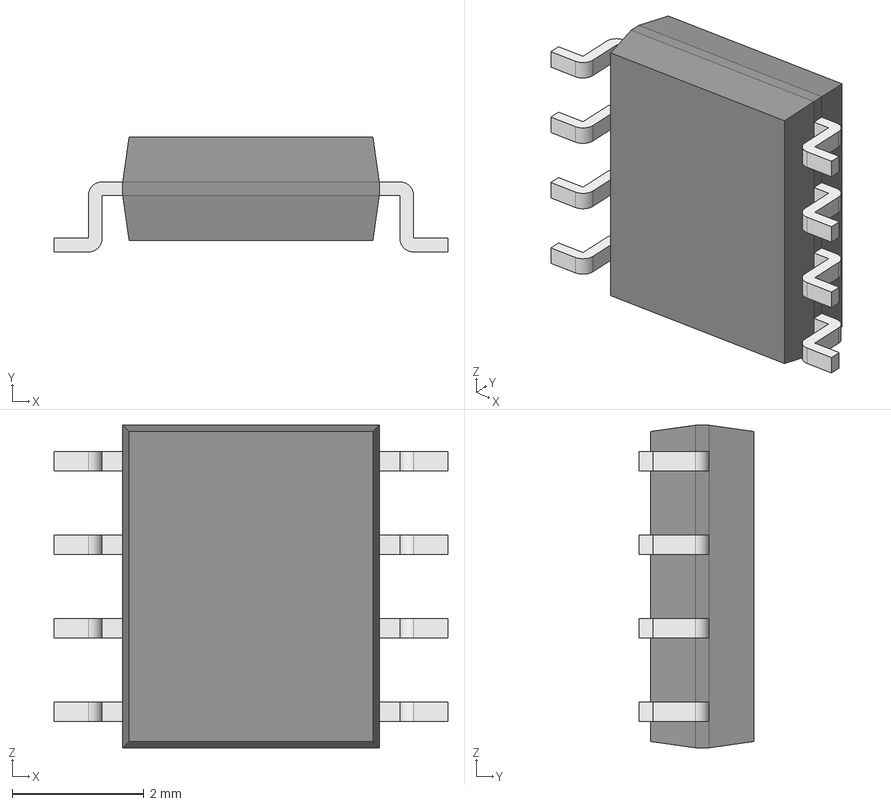
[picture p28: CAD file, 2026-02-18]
Hardware/KICAD_HELIOS/Composants_Helios_KiCad/LM3404MA/LM3404MA.step
5.99 x 1.75 x 4.91 mm
Body001 (Mirror #1) x 4
XY-plane x 12
X-axis x 12

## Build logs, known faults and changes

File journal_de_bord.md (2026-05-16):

## Journal de bord :
# 1ere séance : 02/02/2026
-	Présentation du projet et des objectifs
-   Choix du projet : Strobe lumineux
-	Prise en main du projet
-	Prise en main de GitHub et mise en place de l'architecture
-	Recherche de composants : plusieurs LEDs
# 2e séance : 09/02/2026
-	Recherche de Datasheet
-	Calculs : nombre de LEDs, cohérence avec la puissance…
-	Datasheet/projet qui ressemble au nôtre
-	Calculs techniques
-	Début du schématique du PCB
-	Recherche des composants dans l’inventaire (écran OLED, bouton poussoir, connecteurs mâle et femelle) 
-	Découverte de la commande DMX
# 3e séance : 16/02/2026
-	Choix des LEDs RGB
-	Schématique du PCB
-	Création de plusieurs fichiers « enfant » au niveau du Schématique pour pouvoir faire rentrer les 298 LEDs et les 6 Drivers sur le fichier racine, création de ces fichiers sur plusieurs ordinateurs et assemblage final
# 4e séance : 09/03/2026
-	Schématique du PCB
-	Recherche sur la connectique DMX512
# 5e séance : 16/03/2026
-	Avancée du PCB : routage
-	Recherche des composants dans l’inventaire
-	Modification des éléments de l’alimentation au niveau du Schematic
-	Début des codes pour le Software
# 6e séance : 30/03/2026
-	Avancée du PCB : routage et finalisation
-	Début des codes 
-	Modification des empreintes en fonction de l’inventaire
# 7e séance : 13/04/2026
-	Finalisation PCB
-	Commande du PCB
-	Codes pour le Software
# 8e séance : 04/05/2026
-	Recherche des composants commandés à l'ENSEA
-	Avancement sur le code
# 9e séance : 11/05/2026
-	Fablab ouvert: Soudage avec pâte à braser et four ainsi que fer à souder et étain
-	Mise à jour du Github 
-	Avancement sur le code
# 10e séance : 18/05/2026
- Vérification de la présence ou non de court-circuits (avec multimètre)
- Test des codes
-	Présentation du projet 1A

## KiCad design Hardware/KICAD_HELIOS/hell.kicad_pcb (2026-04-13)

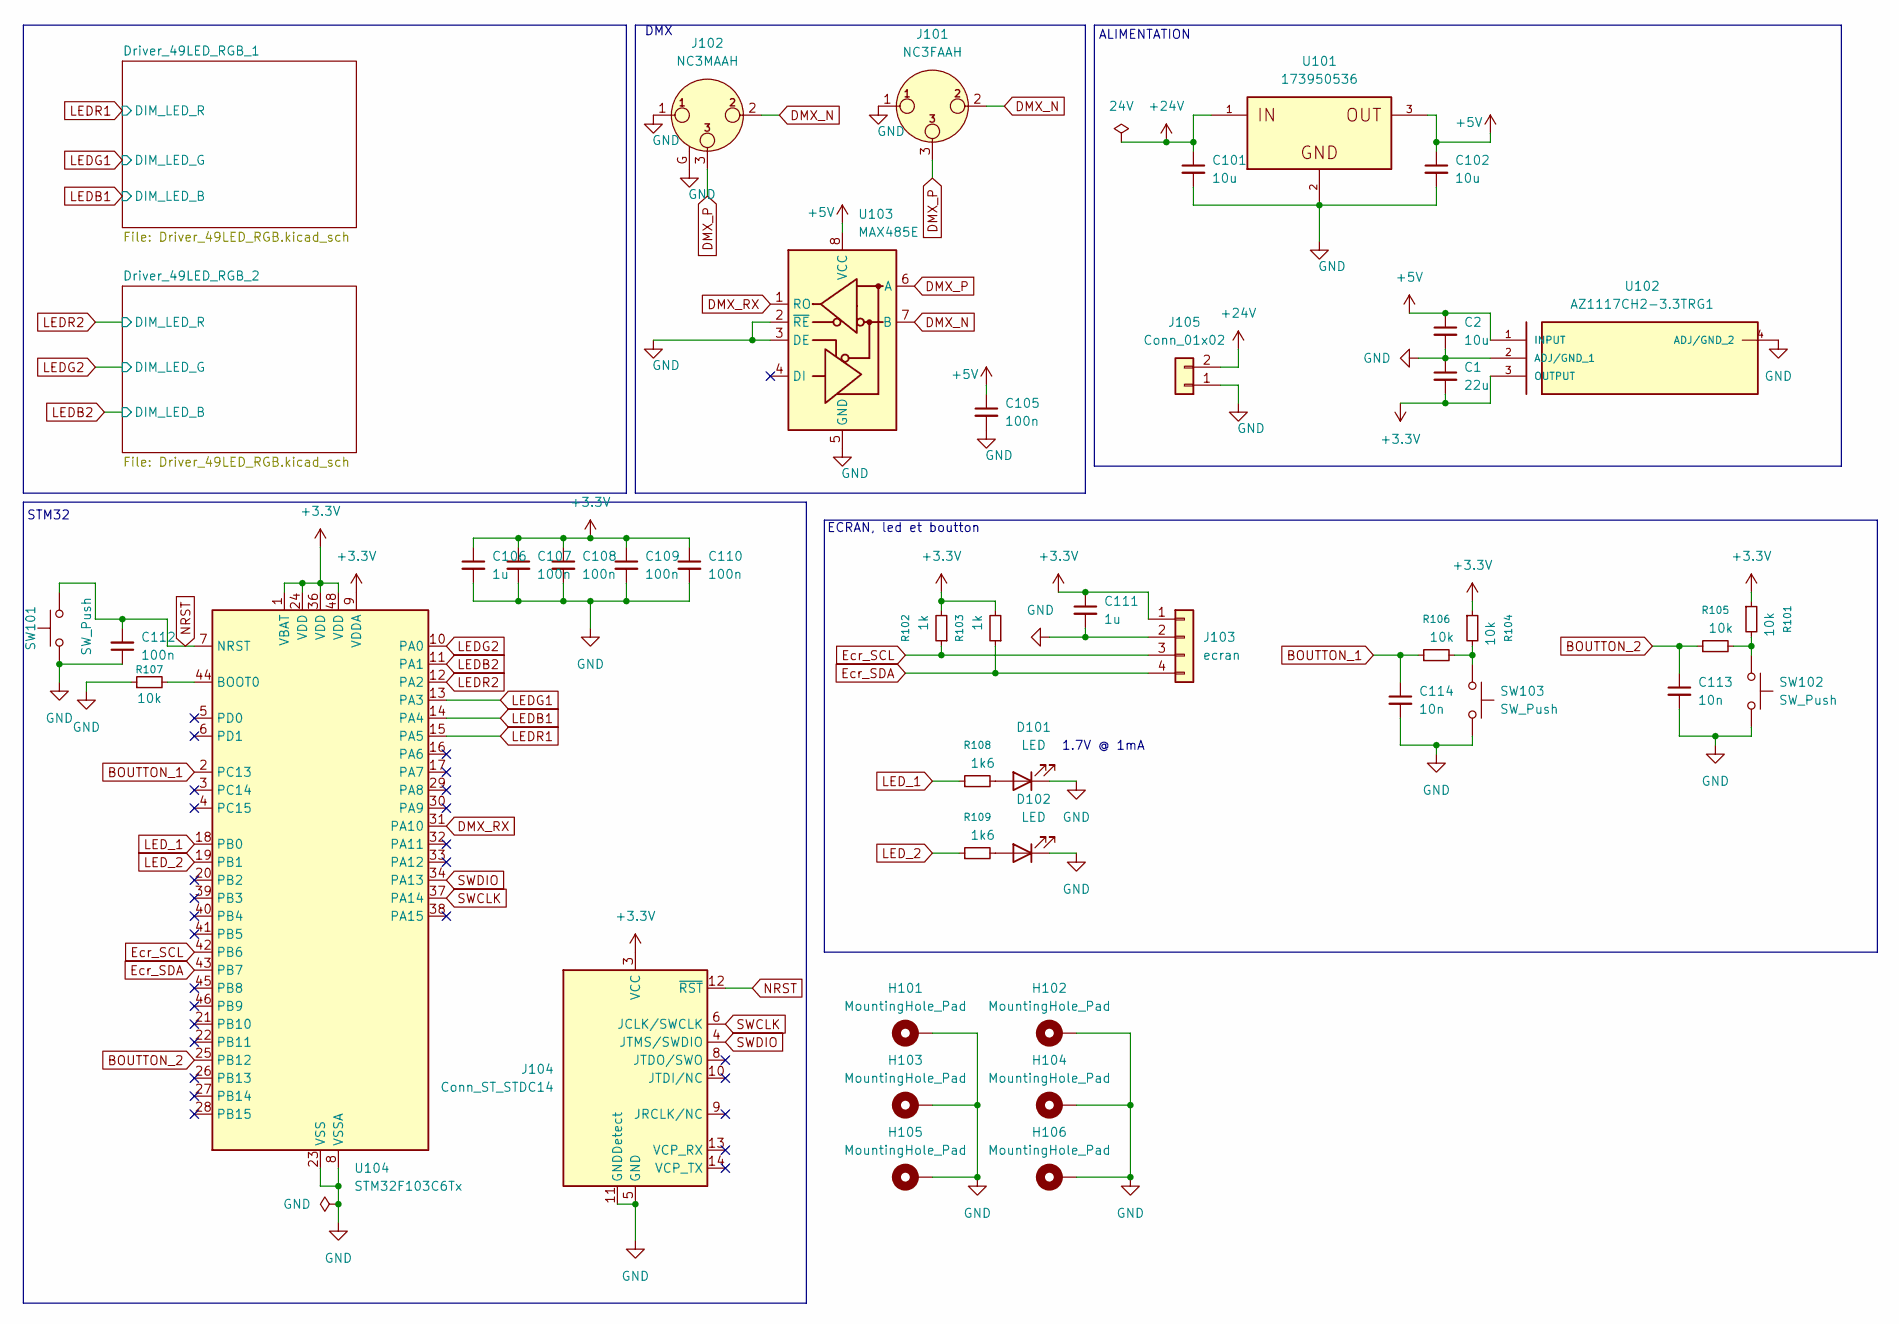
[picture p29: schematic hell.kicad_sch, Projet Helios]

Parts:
C1: 22u; C_0805_2012Metric
C2, C102: 10u; C_0603_1608Metric
C101: 10u; C_1206_3216Metric
C105, C107, C108, C109, C110, C112: 100n; C_0402_1005Metric
C106, C111: 1u; C_0402_1005Metric
C113, C114: 10n; C_0402_1005Metric
D101, D102: LED; LED_0603_1608Metric; MPN 150060RS55040
H101, H102, H103, H104, H105, H106: MountingHole_Pad; MountingHole_3.2mm_M3_DIN965_Pad
J101: NC3FAAH; Jack_XLR_Neutrik_NC3FAAH_Horizontal
J102: NC3MAAH; Jack_XLR_Neutrik_NC3MAAH_Horizontal
J103: ecran; PinHeader_1x05_P2.54mm_Vertical
J104: Conn_ST_STDC14; PinHeader_2x07_P1.27mm_Vertical_SMD
J105: Conn_01x02; AMASS_XT30U-M_1x02_P5.0mm_Vertical
R101, R104, R105, R106, R107: 10k; R_0603_1608Metric
R102, R103: 1k; R_0603_1608Metric
R108, R109: 1k6; R_0603_1608Metric
SW101, SW102, SW103: SW_Push; SW_PUSH_6mm
U101: 173950536; WPME-FDSM_173950536
U102: AZ1117CH2-3.3TRG1; SOT230P700X180-4N; MOUSER_PART_NUMBER 621-AZ1117CH2-33TRG1
U103: MAX485E; SOIC-8_3.9x4.9mm_P1.27mm; MPN MAX485E
U104: STM32F103C6Tx; LQFP-48_7x7mm_P0.5mm

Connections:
+3.3V: C1.2, C106.1, C107.1, C108.1, C109.1, C110.1, C111.1, J103.1, J104.3 (VCC), R101.1, R102.2, R103.2, R104.1, U102.3 (OUTPUT), U104.1 (VBAT), U104.9 (VDDA), U104.24 (VDD), U104.36 (VDD), U104.48 (VDD)
+5V: C2.1, C102.1, C105.1, U101.3, U102.1 (INPUT), U103.8 (VCC)
+24V: C101.1, J105.2, U101.1; also elsewhere on the board
BOUTTON_1: C114.1, R106.1, U104.2 (PC13)
BOUTTON_2: C113.1, R105.1, U104.25 (PB12)
DMX_N: J101.2, J102.2, U103.7 (B)
DMX_P: J101.3, J102.3, U103.6 (A)
DMX_RX: U103.1 (RO), U104.31 (PA10)
Ecr_SCL: J103.3, R102.1, U104.42 (PB6)
Ecr_SDA: J103.4, R103.1, U104.43 (PB7)
GND: C1.1, C2.2, C101.2, C102.2, C105.2, C106.2, C107.2, C108.2, C109.2, C110.2, C111.2, C112.1, C113.2, C114.2, D101.1 (K), D102.1 (K), H101.1, H102.1, H103.1, H104.1, H105.1, H106.1, J101.1, J102.1, J102.G, J103.2, J104.5 (GND), J104.7 (GND), J104.11 (GNDDetect), J105.1, R107.1, SW101.1, SW102.2, SW103.2, U101.2, U102.2 (ADJ/GND_1), U102.4 (ADJ/GND_2), U103.2 (~RE), U103.3 (DE), U103.5 (GND), U104.8 (VSSA), U104.23 (VSS), U104.35 (VSS), U104.47 (VSS); also elsewhere on the board
LEDB1: U104.14 (PA4); also elsewhere on the board
LEDB2: U104.11 (PA1); also elsewhere on the board
LEDG1: U104.13 (PA3); also elsewhere on the board
LEDG2: U104.10 (PA0); also elsewhere on the board
LEDR1: U104.15 (PA5); also elsewhere on the board
LEDR2: U104.12 (PA2); also elsewhere on the board
LED_1: R108.1, U104.18 (PB0)
LED_2: R109.1, U104.19 (PB1)
NRST: C112.2, J104.12 (~RST), SW101.2, U104.7 (NRST)
unnamed: D101.2 (A), R108.2
unnamed: D102.2 (A), R109.2
unnamed: R101.2, R105.2, SW102.1
unnamed: R104.2, R106.2, SW103.1
unnamed: R107.2, U104.44 (BOOT0)
SWCLK: J104.6 (JCLK/SWCLK), U104.37 (PA14)
SWDIO: J104.4 (JTMS/SWDIO), U104.34 (PA13)

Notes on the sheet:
ALIMENTATION
1.7V @ 1mA
STM32
DMX
ECRAN, led et boutton

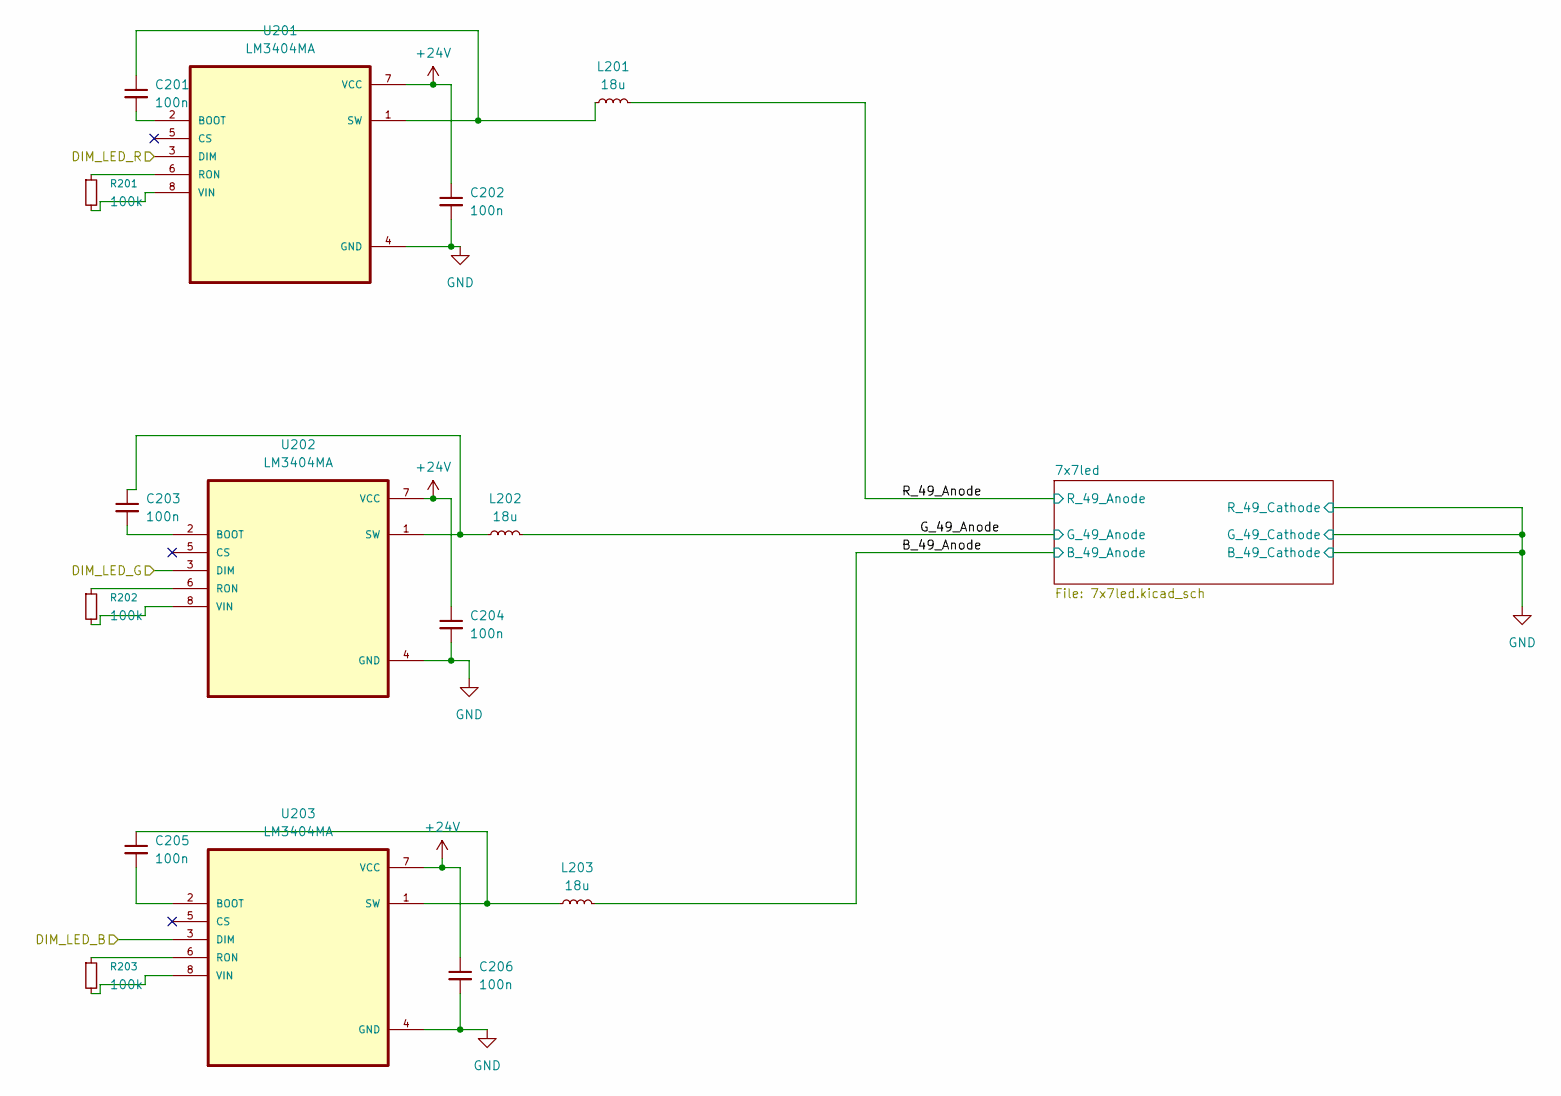
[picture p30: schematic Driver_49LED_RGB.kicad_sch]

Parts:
C201, C202, C203, C204, C205, C206: 100n; C_0603_1608Metric
L201, L202, L203: 18u; L_1210_3225Metric; MPN 744032180
R201, R202, R203: 100k; R_0603_1608Metric
U201, U203: LM3404MA; SOIC127P599X175-8N
U202: LM3404MA; SOIC127P599X175-8N; MPN LM3404MA

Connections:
+24V: C202.1, C204.1, C206.1, U201.7 (VCC), U202.7 (VCC), U203.7 (VCC); also elsewhere on the board
/Driver_49LED_RGB_1/B_49_Anode: L203.2; also elsewhere on the board
/Driver_49LED_RGB_1/G_49_Anode: L202.2; also elsewhere on the board
/Driver_49LED_RGB_1/R_49_Anode: L201.2; also elsewhere on the board
GND: C202.2, C204.2, C206.2, U201.4 (GND), U202.4 (GND), U203.4 (GND); also elsewhere on the board
LEDB1: U203.3 (DIM); also elsewhere on the board
LEDG1: U202.3 (DIM); also elsewhere on the board
LEDR1: U201.3 (DIM); also elsewhere on the board
unnamed: C201.2, U201.2 (BOOT)
unnamed: R201.1, U201.6 (RON)
unnamed: C201.1, L201.1, U201.1 (SW)
unnamed: R201.2, U201.8 (VIN)
unnamed: C203.2, U202.2 (BOOT)
unnamed: R202.1, U202.6 (RON)
unnamed: C203.1, L202.1, U202.1 (SW)
unnamed: R202.2, U202.8 (VIN)
unnamed: C205.2, U203.2 (BOOT)
unnamed: R203.1, U203.6 (RON)
unnamed: C205.1, L203.1, U203.1 (SW)
unnamed: R203.2, U203.8 (VIN)

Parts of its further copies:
C1101, C1102, C1103, C1104, C1105, C1106: 100n; C_0603_1608Metric
L1101, L1102, L1103: 18u; L_1210_3225Metric; MPN 744032180
R1101, R1102, R1103: 100k; R_0603_1608Metric
U1101, U1103: LM3404MA; SOIC127P599X175-8N
U1102: LM3404MA; SOIC127P599X175-8N; MPN LM3404MA

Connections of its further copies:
+24V: C1102.1, C1104.1, C1106.1, U1101.7 (VCC), U1102.7 (VCC), U1103.7 (VCC); also elsewhere on the board
/Driver_49LED_RGB_2/B_49_Anode: L1103.2; also elsewhere on the board
/Driver_49LED_RGB_2/G_49_Anode: L1102.2; also elsewhere on the board
/Driver_49LED_RGB_2/R_49_Anode: L1101.2; also elsewhere on the board
GND: C1102.2, C1104.2, C1106.2, U1101.4 (GND), U1102.4 (GND), U1103.4 (GND); also elsewhere on the board
LEDB2: U1103.3 (DIM); also elsewhere on the board
LEDG2: U1102.3 (DIM); also elsewhere on the board
LEDR2: U1101.3 (DIM); also elsewhere on the board
unnamed: C1101.2, U1101.2 (BOOT)
unnamed: R1101.1, U1101.6 (RON)
unnamed: C1101.1, L1101.1, U1101.1 (SW)
unnamed: R1101.2, U1101.8 (VIN)
unnamed: C1103.2, U1102.2 (BOOT)
unnamed: R1102.1, U1102.6 (RON)
unnamed: C1103.1, L1102.1, U1102.1 (SW)
unnamed: R1102.2, U1102.8 (VIN)
unnamed: C1105.2, U1103.2 (BOOT)
unnamed: R1103.1, U1103.6 (RON)
unnamed: C1105.1, L1103.1, U1103.1 (SW)
unnamed: R1103.2, U1103.8 (VIN)

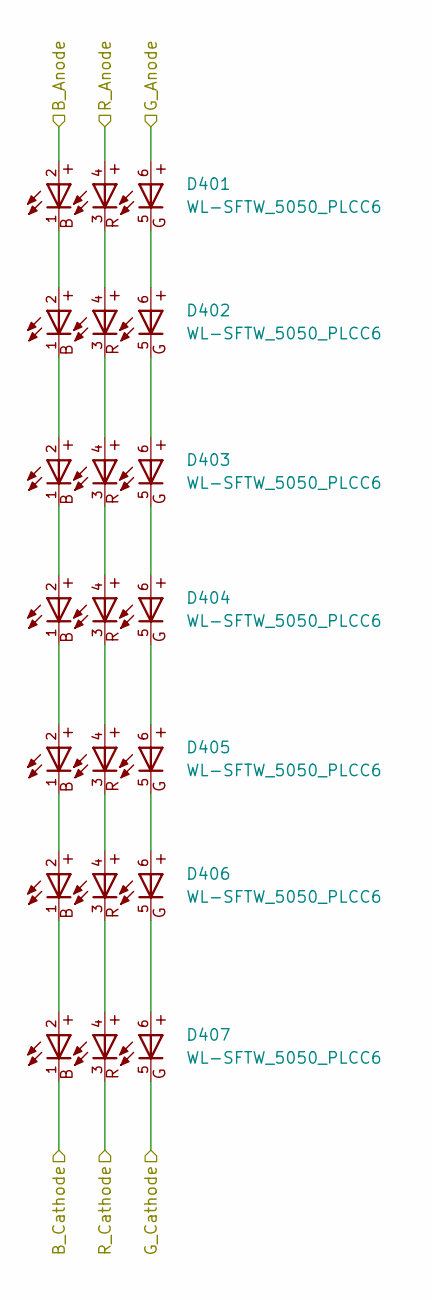
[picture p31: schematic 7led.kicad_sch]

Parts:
D401, D402, D403, D404, D405, D406, D407: WL-SFTW_5050_PLCC6; DigiKey_Part_Number 732-12000-1-ND

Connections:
/Driver_49LED_RGB_1/B_49_Anode: D401.2; also elsewhere on the board
/Driver_49LED_RGB_1/G_49_Anode: D401.6; also elsewhere on the board
/Driver_49LED_RGB_1/R_49_Anode: D401.4; also elsewhere on the board
GND: D407.1, D407.3, D407.5; also elsewhere on the board
unnamed: D401.1, D402.2
unnamed: D401.3, D402.4
unnamed: D401.5, D402.6
unnamed: D402.1, D403.2
unnamed: D402.3, D403.4
unnamed: D402.5, D403.6
unnamed: D403.1, D404.2
unnamed: D403.3, D404.4
unnamed: D403.5, D404.6
unnamed: D404.1, D405.2
unnamed: D404.3, D405.4
unnamed: D404.5, D405.6
unnamed: D405.1, D406.2
unnamed: D405.3, D406.4
unnamed: D405.5, D406.6
unnamed: D406.1, D407.2
unnamed: D406.3, D407.4
unnamed: D406.5, D407.6

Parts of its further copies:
D501, D502, D503, D504, D505, D506, D507, D601, D602, D603, D604, D605, D606, D607, D701, D702, D703, D704, D705, D706, D707, D801, D802, D803, D804, D805, D806, D807, D901, D902, D903, D904, D905, D906, D907, D1001, D1002, D1003, D1004, D1005, D1006, D1007, D1301, D1302, D1303, D1304, D1305, D1306, D1307, D1401, D1402, D1403, D1404, D1405, D1406, D1407, D1501, D1502, D1503, D1504, D1505, D1506, D1507, D1601, D1602, D1603, D1604, D1605, D1606, D1607, D1701, D1702, D1703, D1704, D1705, D1706, D1707, D1801, D1802, D1803, D1804, D1805, D1806, D1807, D1901, D1902, D1903, D1904, D1905, D1906, D1907: WL-SFTW_5050_PLCC6; DigiKey_Part_Number 732-12000-1-ND

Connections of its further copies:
/Driver_49LED_RGB_1/B_49_Anode: D501.2, D601.2, D701.2, D801.2, D901.2, D1001.2; also elsewhere on the board
/Driver_49LED_RGB_1/G_49_Anode: D501.6, D601.6, D701.6, D801.6, D901.6, D1001.6; also elsewhere on the board
/Driver_49LED_RGB_1/R_49_Anode: D501.4, D601.4, D701.4, D801.4, D901.4, D1001.4; also elsewhere on the board
/Driver_49LED_RGB_2/B_49_Anode: D1301.2, D1401.2, D1501.2, D1601.2, D1701.2, D1801.2, D1901.2; also elsewhere on the board
/Driver_49LED_RGB_2/G_49_Anode: D1301.6, D1401.6, D1501.6, D1601.6, D1701.6, D1801.6, D1901.6; also elsewhere on the board
/Driver_49LED_RGB_2/R_49_Anode: D1301.4, D1401.4, D1501.4, D1601.4, D1701.4, D1801.4, D1901.4; also elsewhere on the board
GND: D507.1, D507.3, D507.5, D607.1, D607.3, D607.5, D707.1, D707.3, D707.5, D807.1, D807.3, D807.5, D907.1, D907.3, D907.5, D1007.1, D1007.3, D1007.5, D1307.1, D1307.3, D1307.5, D1407.1, D1407.3, D1407.5, D1507.1, D1507.3, D1507.5, D1607.1, D1607.3, D1607.5, D1707.1, D1707.3, D1707.5, D1807.1, D1807.3, D1807.5, D1907.1, D1907.3, D1907.5; also elsewhere on the board
unnamed: D501.1, D502.2
unnamed: D501.3, D502.4
unnamed: D501.5, D502.6
unnamed: D502.1, D503.2
unnamed: D502.3, D503.4
unnamed: D502.5, D503.6
unnamed: D503.1, D504.2
unnamed: D503.3, D504.4
unnamed: D503.5, D504.6
unnamed: D504.1, D505.2
unnamed: D504.3, D505.4
unnamed: D504.5, D505.6
unnamed: D505.1, D506.2
unnamed: D505.3, D506.4
unnamed: D505.5, D506.6
unnamed: D506.1, D507.2
unnamed: D506.3, D507.4
unnamed: D506.5, D507.6
unnamed: D601.1, D602.2
unnamed: D601.3, D602.4
unnamed: D601.5, D602.6
unnamed: D602.1, D603.2
unnamed: D602.3, D603.4
unnamed: D602.5, D603.6
unnamed: D603.1, D604.2
unnamed: D603.3, D604.4
unnamed: D603.5, D604.6
unnamed: D604.1, D605.2
unnamed: D604.3, D605.4
unnamed: D604.5, D605.6
unnamed: D605.1, D606.2
unnamed: D605.3, D606.4
unnamed: D605.5, D606.6
unnamed: D606.1, D607.2
unnamed: D606.3, D607.4
unnamed: D606.5, D607.6
unnamed: D701.1, D702.2
unnamed: D701.3, D702.4
unnamed: D701.5, D702.6
unnamed: D702.1, D703.2
unnamed: D702.3, D703.4
unnamed: D702.5, D703.6
unnamed: D703.1, D704.2
unnamed: D703.3, D704.4
unnamed: D703.5, D704.6
unnamed: D704.1, D705.2
unnamed: D704.3, D705.4
unnamed: D704.5, D705.6
unnamed: D705.1, D706.2
unnamed: D705.3, D706.4
unnamed: D705.5, D706.6
unnamed: D706.1, D707.2
unnamed: D706.3, D707.4
unnamed: D706.5, D707.6
unnamed: D801.1, D802.2
unnamed: D801.3, D802.4
unnamed: D801.5, D802.6
unnamed: D802.1, D803.2
unnamed: D802.3, D803.4
unnamed: D802.5, D803.6
unnamed: D803.1, D804.2
unnamed: D803.3, D804.4
unnamed: D803.5, D804.6
unnamed: D804.1, D805.2
unnamed: D804.3, D805.4
unnamed: D804.5, D805.6
unnamed: D805.1, D806.2
unnamed: D805.3, D806.4
unnamed: D805.5, D806.6
unnamed: D806.1, D807.2
unnamed: D806.3, D807.4
unnamed: D806.5, D807.6
unnamed: D901.1, D902.2
unnamed: D901.3, D902.4
unnamed: D901.5, D902.6
unnamed: D902.1, D903.2
unnamed: D902.3, D903.4
unnamed: D902.5, D903.6
unnamed: D903.1, D904.2
unnamed: D903.3, D904.4
unnamed: D903.5, D904.6
unnamed: D904.1, D905.2
unnamed: D904.3, D905.4
unnamed: D904.5, D905.6
unnamed: D905.1, D906.2
unnamed: D905.3, D906.4
unnamed: D905.5, D906.6
unnamed: D906.1, D907.2
unnamed: D906.3, D907.4
unnamed: D906.5, D907.6
unnamed: D1001.1, D1002.2
unnamed: D1001.3, D1002.4
unnamed: D1001.5, D1002.6
unnamed: D1002.1, D1003.2
unnamed: D1002.3, D1003.4
unnamed: D1002.5, D1003.6
unnamed: D1003.1, D1004.2
unnamed: D1003.3, D1004.4
unnamed: D1003.5, D1004.6
unnamed: D1004.1, D1005.2
unnamed: D1004.3, D1005.4
unnamed: D1004.5, D1005.6
unnamed: D1005.1, D1006.2
unnamed: D1005.3, D1006.4
unnamed: D1005.5, D1006.6
unnamed: D1006.1, D1007.2
unnamed: D1006.3, D1007.4
unnamed: D1006.5, D1007.6
unnamed: D1301.1, D1302.2
unnamed: D1301.3, D1302.4
unnamed: D1301.5, D1302.6
unnamed: D1302.1, D1303.2
unnamed: D1302.3, D1303.4
unnamed: D1302.5, D1303.6
unnamed: D1303.1, D1304.2
unnamed: D1303.3, D1304.4
unnamed: D1303.5, D1304.6
unnamed: D1304.1, D1305.2
unnamed: D1304.3, D1305.4
unnamed: D1304.5, D1305.6
unnamed: D1305.1, D1306.2
unnamed: D1305.3, D1306.4
unnamed: D1305.5, D1306.6
unnamed: D1306.1, D1307.2
unnamed: D1306.3, D1307.4
unnamed: D1306.5, D1307.6
unnamed: D1401.1, D1402.2
unnamed: D1401.3, D1402.4
unnamed: D1401.5, D1402.6
unnamed: D1402.1, D1403.2
unnamed: D1402.3, D1403.4
unnamed: D1402.5, D1403.6
unnamed: D1403.1, D1404.2
unnamed: D1403.3, D1404.4
unnamed: D1403.5, D1404.6
unnamed: D1404.1, D1405.2
unnamed: D1404.3, D1405.4
unnamed: D1404.5, D1405.6
unnamed: D1405.1, D1406.2
unnamed: D1405.3, D1406.4
unnamed: D1405.5, D1406.6
unnamed: D1406.1, D1407.2
unnamed: D1406.3, D1407.4
unnamed: D1406.5, D1407.6
unnamed: D1501.1, D1502.2
unnamed: D1501.3, D1502.4
unnamed: D1501.5, D1502.6
unnamed: D1502.1, D1503.2
unnamed: D1502.3, D1503.4
unnamed: D1502.5, D1503.6
unnamed: D1503.1, D1504.2
unnamed: D1503.3, D1504.4
unnamed: D1503.5, D1504.6
unnamed: D1504.1, D1505.2
unnamed: D1504.3, D1505.4
unnamed: D1504.5, D1505.6
unnamed: D1505.1, D1506.2
unnamed: D1505.3, D1506.4
unnamed: D1505.5, D1506.6
unnamed: D1506.1, D1507.2
unnamed: D1506.3, D1507.4
unnamed: D1506.5, D1507.6
unnamed: D1601.1, D1602.2
unnamed: D1601.3, D1602.4
unnamed: D1601.5, D1602.6
unnamed: D1602.1, D1603.2
unnamed: D1602.3, D1603.4
unnamed: D1602.5, D1603.6
unnamed: D1603.1, D1604.2
unnamed: D1603.3, D1604.4
unnamed: D1603.5, D1604.6
unnamed: D1604.1, D1605.2
unnamed: D1604.3, D1605.4
unnamed: D1604.5, D1605.6
unnamed: D1605.1, D1606.2
unnamed: D1605.3, D1606.4
unnamed: D1605.5, D1606.6
unnamed: D1606.1, D1607.2
unnamed: D1606.3, D1607.4
unnamed: D1606.5, D1607.6
unnamed: D1701.1, D1702.2
unnamed: D1701.3, D1702.4
unnamed: D1701.5, D1702.6
unnamed: D1702.1, D1703.2
unnamed: D1702.3, D1703.4
unnamed: D1702.5, D1703.6
unnamed: D1703.1, D1704.2
unnamed: D1703.3, D1704.4
unnamed: D1703.5, D1704.6
unnamed: D1704.1, D1705.2
unnamed: D1704.3, D1705.4
unnamed: D1704.5, D1705.6
unnamed: D1705.1, D1706.2
unnamed: D1705.3, D1706.4
unnamed: D1705.5, D1706.6
unnamed: D1706.1, D1707.2
unnamed: D1706.3, D1707.4
unnamed: D1706.5, D1707.6
unnamed: D1801.1, D1802.2
unnamed: D1801.3, D1802.4
unnamed: D1801.5, D1802.6
unnamed: D1802.1, D1803.2
unnamed: D1802.3, D1803.4
unnamed: D1802.5, D1803.6
unnamed: D1803.1, D1804.2
unnamed: D1803.3, D1804.4
unnamed: D1803.5, D1804.6
unnamed: D1804.1, D1805.2
unnamed: D1804.3, D1805.4
unnamed: D1804.5, D1805.6
unnamed: D1805.1, D1806.2
unnamed: D1805.3, D1806.4
unnamed: D1805.5, D1806.6
unnamed: D1806.1, D1807.2
unnamed: D1806.3, D1807.4
unnamed: D1806.5, D1807.6
unnamed: D1901.1, D1902.2
unnamed: D1901.3, D1902.4
unnamed: D1901.5, D1902.6
unnamed: D1902.1, D1903.2
unnamed: D1902.3, D1903.4
unnamed: D1902.5, D1903.6
unnamed: D1903.1, D1904.2
unnamed: D1903.3, D1904.4
unnamed: D1903.5, D1904.6
unnamed: D1904.1, D1905.2
unnamed: D1904.3, D1905.4
unnamed: D1904.5, D1905.6
unnamed: D1905.1, D1906.2
unnamed: D1905.3, D1906.4
unnamed: D1905.5, D1906.6
unnamed: D1906.1, D1907.2
unnamed: D1906.3, D1907.4
unnamed: D1906.5, D1907.6

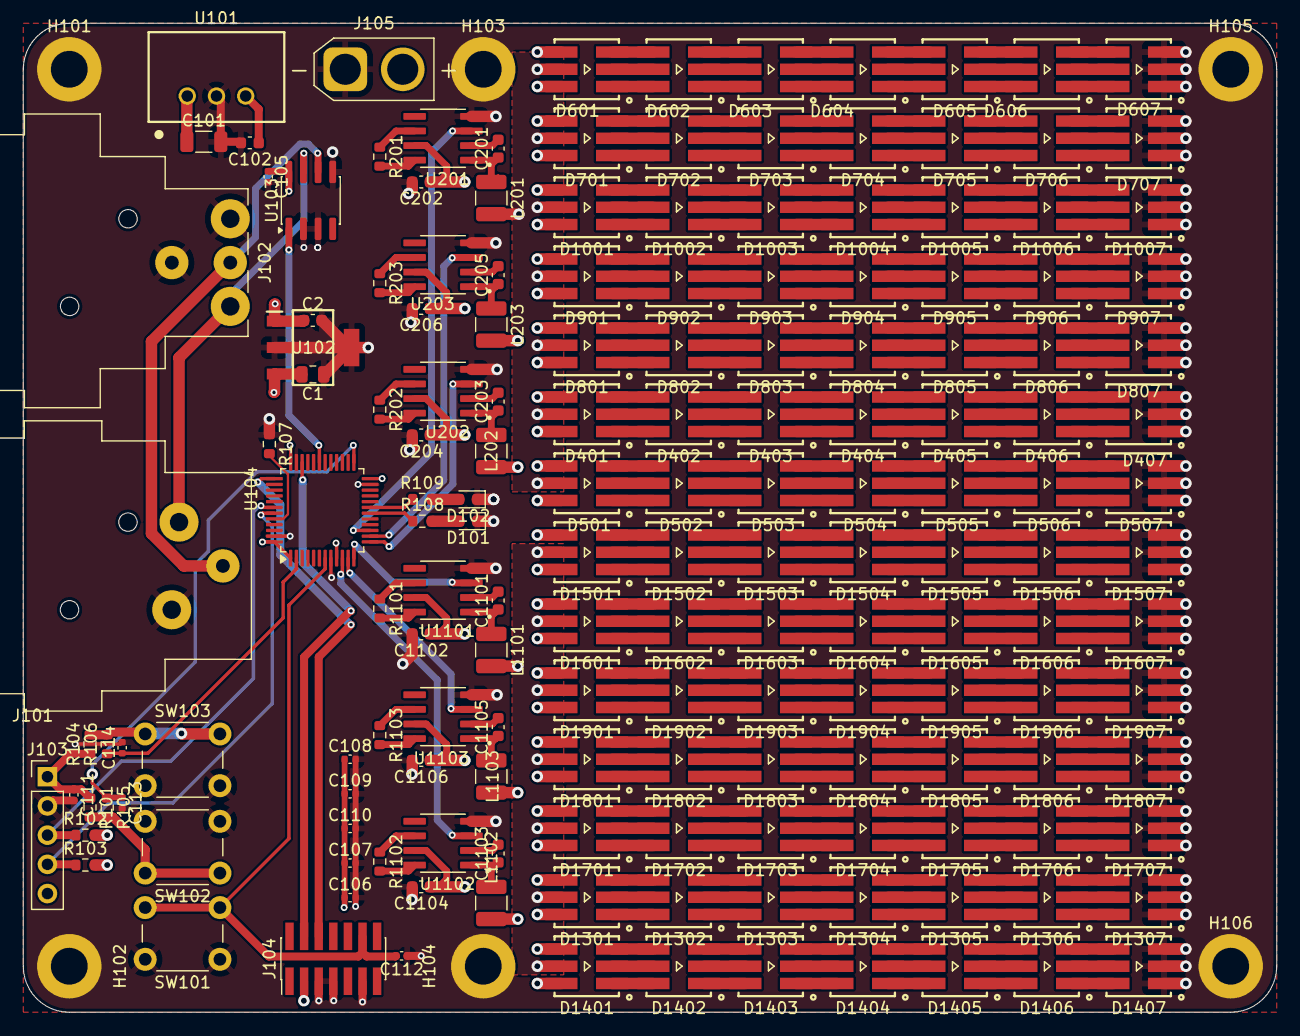
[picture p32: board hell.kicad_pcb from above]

Board: 4 copper layers, 109.0 x 86.0 mm, 171 parts (0 on the bottom side), 309 nets.

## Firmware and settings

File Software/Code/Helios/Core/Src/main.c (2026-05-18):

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
/* Includes ------------------------------------------------------------------*/
#include "main.h"
#include "tim.h"
#include "usart.h"
#include "gpio.h"

/* USER CODE BEGIN Includes */
#include "dmx.h"
#include "dmx_parsec.h"
#include "strobe.h"
/* USER CODE END Includes */


void SystemClock_Config(void);
/**
  * @brief  The application entry point.
  * @retval int
  */
int main(void)
{

  /* MCU Configuration--------------------------------------------------------*/

  /* Reset of all peripherals, Initializes the Flash interface and the Systick. */
  HAL_Init();

  /* Configure the system clock */
  SystemClock_Config();

  /* Initialize all configured peripherals */
  MX_GPIO_Init();
  MX_USART1_UART_Init();
  MX_TIM2_Init();
  MX_TIM3_Init();
  /* USER CODE BEGIN 2 */

  DMX_Init();

  STROBE_Init();

  DMX_StartReception();

  /* USER CODE END 2 */

  /* Infinite loop */
  /* USER CODE BEGIN WHILE */
  while (1)
  {
	  /*
	    if(DMX_NewFrameAvailable())
	    {
			/* TEST LED */
	    	/*
			HAL_GPIO_TogglePin(
					LED1_GPIO_Port,
					LED1_Pin
			);

	        __HAL_TIM_SET_COMPARE(
	            &htim2,
	            TIM_CHANNEL_1,
	            DMX_GetChannel(1)
	        );

	        DMX_ClearFrameFlag();
	    }*/

	  if(DMX_NewFrameAvailable())
	      {
	          DMX_ParseFrame();

	          STROBE_Update(
	              DMX_GetParsedData()
	          );

	          DMX_ClearFrameFlag();
	      }

    /* USER CODE END WHILE */

    /* USER CODE BEGIN 3 */
  }
  /* USER CODE END 3 */
}

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


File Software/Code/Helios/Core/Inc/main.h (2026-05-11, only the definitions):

#define Boutton1_Pin GPIO_PIN_13
#define Boutton1_GPIO_Port GPIOC
#define LedR1_Pin GPIO_PIN_0
#define LedR1_GPIO_Port GPIOA
#define LedG1_Pin GPIO_PIN_1
#define LedG1_GPIO_Port GPIOA
#define LedB1_Pin GPIO_PIN_2
#define LedB1_GPIO_Port GPIOA
#define LedR2_Pin GPIO_PIN_3
#define LedR2_GPIO_Port GPIOA
#define LedG2_Pin GPIO_PIN_4
#define LedG2_GPIO_Port GPIOA
#define LedB2_Pin GPIO_PIN_5
#define LedB2_GPIO_Port GPIOA
#define LED1_Pin GPIO_PIN_0
#define LED1_GPIO_Port GPIOB
#define LED2_Pin GPIO_PIN_1
#define LED2_GPIO_Port GPIOB
#define Boutton2_Pin GPIO_PIN_12
#define Boutton2_GPIO_Port GPIOB

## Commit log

2026-02-02 cahier des charges
2026-02-02 Update README.md
    Erreur sur la description du strobe
2026-02-02 Suppression de l'ancien dossier dataset
2026-02-09 Add the datasheet file of the LED driver
    The only LED driver directly available at school
2026-02-09 choix de la LED
2026-02-16 Datasheet for the Buck step down
    We use a Buck to go from 24V to 5V because a FDO would be inefficient and would disperse more heat.
2026-02-16 Rename non utilisée.pdf to LED_150505M173300.pdf
2026-02-16 Version PCB - non utilisée
    [PCB projet.kicad_pcb, PCB projet.kicad_sch]
2026-02-16 création du dossier kicad et ajout de la version sans led et drivers
    [hell.kicad_pcb, hell.kicad_sch]
2026-02-18 schématique combiné
    [hell.kicad_pcb, hell.kicad_sch]
2026-02-18 Fix: correction erreurs schéma, maj empreintes et ajout notes
    - Résolution de toutes les erreurs ERC du schéma.
    - Mise à jour des empreintes (Importation d'empreintes non présentes dans KiCad, composants passifs...).
    - Ajout de Warning_KiCad_fichier_temporaire.md : liste des questions et problèmes à régler.
    [7led.kicad_sch, Driver_49LED_RGB.kicad_sch, LM3404MA.step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]
2026-02-18 Update status to include full schematic validation
2026-02-19 correction bug lié aux empreinte (dossier composant mit dans kicad)
    [LM3404MA.step, WL-SFTW_5050_PLCC6.step]
2026-02-19 changement à faire schématic
    [Driver_49LED_RGB.kicad_sch, hell.kicad_sch]
2026-03-09 correction (reste à calculer L)
    [hell.kicad_sch]
2026-03-09 schématic finie
    [Driver_49LED_RGB.kicad_sch, hell.kicad_sch]
2026-03-09 schematic + empreinte
    [hell.kicad_sch]
2026-03-09 Update README with project summary and materials updated
2026-03-09 organisation routage
    [hell.kicad_pcb]
2026-03-16 PCB Routage 1ver
    [hell.kicad_pcb]
2026-03-16 update pcb
    [7led.kicad_sch, Driver_49LED_RGB.kicad_sch, hell.kicad_pcb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]
2026-03-16 Liste des composants
2026-03-16 Kicad PCB et changement de quelques empreintes
    [Driver_49LED_RGB.kicad_sch, hell.kicad_pcb, hell.kicad_sch]
2026-03-30 Routage presque fini en attente de modification d'empreinte
    [Driver_49LED_RGB.kicad_sch, hell.kicad_pcb, hell.kicad_sch]
2026-03-30 Routage PCB en prenant en compte la place mécanique des composants
    [hell.kicad_pcb, hell.kicad_sch]
2026-04-13 pcb pour impression
    [hell-B_Cu.gbr, hell-B_Mask.gbr, hell-B_Paste.gbr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]
2026-04-13 Update journal_de_bord.md
    Déroulé des séances
2026-05-06 bonne datasheet pour la LED
    [hell-B_Cu.gbr, hell-B_Mask.gbr, hell-B_Paste.gbr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]
2026-05-11 Réorganisation des fichiers et Mis à jour du Github
    [7led.kicad_sch, 7x7led.kicad_sch, AZ1117CH2-3.3TRG1.step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]
2026-05-16 Régoranisation des datasheets

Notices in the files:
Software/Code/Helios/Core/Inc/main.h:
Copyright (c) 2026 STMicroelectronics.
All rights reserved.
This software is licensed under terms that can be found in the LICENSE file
